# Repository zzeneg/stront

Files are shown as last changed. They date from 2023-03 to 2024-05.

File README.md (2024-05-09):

# stront

Family of modular split keyboards with 38 or 40 keys, LCD display and Cirque/Azoteq trackpad.

## Features

All versions:
- Hotswap sockets
- LCD display (1.69" 240x280 by default)
- Cirque or Azoteq (with VIK adapter) trackpad
- roller/rotary encoders
- 3D printed cases
- exposed SPI/I2C contacts, so any other device can be used instead, it's just a matter of changing the case

| | MX-40 | MX-38 | Choc |
| --- | --- | --- | --- |
| Number of keys | 40 | 38 | 38 |
| Supported switches | MX/KS<sup>[1]</sup>| MX/KS<sup>[1]</sup>| Choc v1 |
| Interconnect | USB-C | USB-C/TRRS | USB-C/TRRS |
| Interconnect | USB-C | USB-C/TRRS | USB-C/TRRS |
| [VIK](https://github.com/sadekbaroudi/vik) support | :heavy_check_mark: | :heavy_check_mark: | :x: |
| Module system | :heavy_check_mark: | :heavy_check_mark: | :x: |
| Splay | :x: | :x: | :heavy_check_mark: |

**[1]**: KS-33/KS-27 - Gateron Low Profile switches, not compatible with MX footprint and require special hotswap sockets

## Photos

#### MX-40 and MX-38 versions

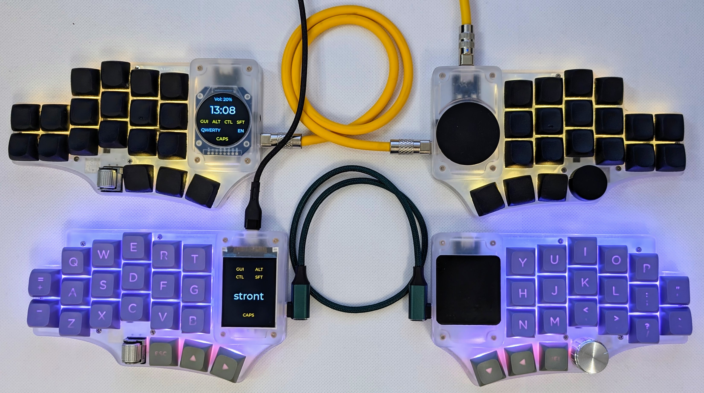
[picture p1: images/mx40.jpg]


#### MX-38 versions (MX and KS-33 switches)

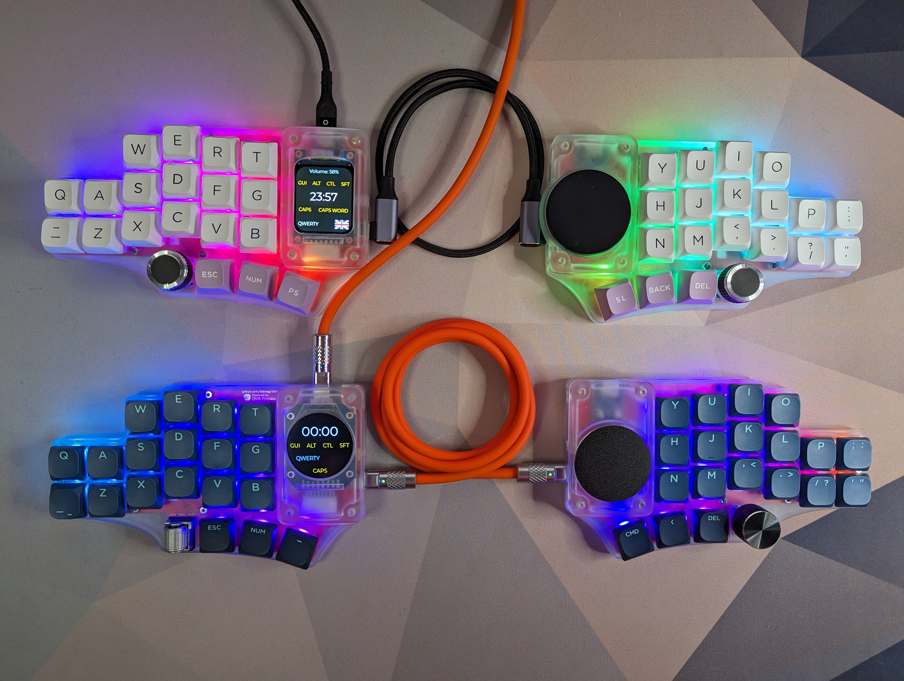
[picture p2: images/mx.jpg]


#### Choc version

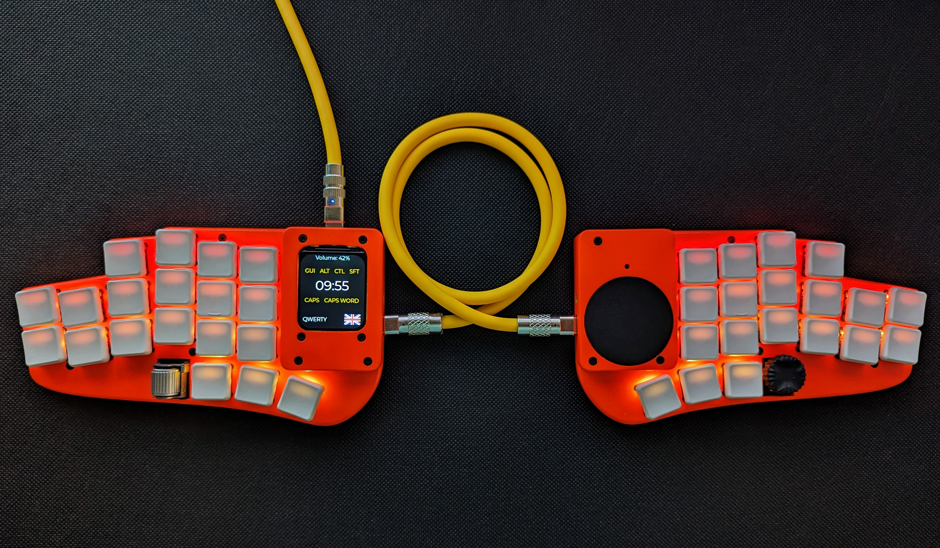
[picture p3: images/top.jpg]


#### Display with PC companion app

https://github.com/zzeneg/stront/assets/910255/bb812821-9b2b-454a-a9a5-45d696a1f5aa

## Available modules - MX38/MX40 versions only ⚠️

- LCD displays
  - ST7789 1.69" 240x280
  - ST7789 2" 240x320
  - GC9A01 round 1.28" 240x240
- Touchpads
  - Cirque 40mm flat
  - Cirque 40mm curved
  - Azoteq TPS43
  - Azoteq TPS65 (technically supported but I think it's too big)

## Firmware

[Companion app](https://github.com/zzeneg/qmk-hid-host) for Raw HID communication.

#### QMK

Please see main `config.h` and `rules.mk` for comments and available options.

- [source code](https://github.com/zzeneg/qmk_firmware/tree/stront/keyboards/stront)
- [pre-compiled files](https://github.com/zzeneg/qmk_firmware/releases/tag/stront)

#### Vial

- [source code](https://github.com/zzeneg/vial-qmk/tree/feature/zzeneg/keyboards/stront)
- [pre-compiled files](https://github.com/zzeneg/vial-qmk/releases/tag/zzeneg)

#### Compiled versions
> Each firmware name has two modules, first is on the left side, second on the right, e.g. if your keyboard has Azoteq on the left and round display on the right - choose `azoteq-round`

- keymaps:
  - `default` - sample keymap with home row mods. Not recommended for longer use - create your own.
  - `hid` - default keymap with HID support. Requires companion application.
  - `zzeneg` - my highly customized layout.
- hardware versions:
  - `-rect-` - rectangular display (ST7789 240x280)
  - `-round-` - round display (GC9A01 240x240)
  - `-flat-` - flat 40mm Cirque
  - `-curved-` - curved 40mm Cirque
  - `-azoteq-` - Azoteq TPS43

> [!WARNING]
> For 38keys version with VIK display adapter - redefine LCD pins in `config.h` as in 40keys version

## Build Guide

[MX38/MX40 versions](./build-guide/mx/readme.md)

[Choc version](./build-guide/choc/readme.md)

## VIK - MX38/MX40 versions only ⚠️

> [!NOTE]
> VIK is a standard for a data interface between printed circuit boards. It is intended to provide modularity between a mechanical keyboard PCB and additional features.

[VIK repository](https://github.com/sadekbaroudi/vik)

#### Certification card

| Category | Classification | Response |
| --- | --- | --- |
| FPC connector | Required | :heavy_check_mark: |
| Breakout pins | Recommended | :heavy_check_mark: |
| Supplies: SPI | Strongly recommended | :heavy_check_mark: <sup>[1]</sup> |
| Supplies: I2C | Strongly recommended | :heavy_check_mark: <sup>[1]</sup> |
| I2C on main PCB | Discouraged | No |
| I2C pull ups | Informative | Optional<sup>[2]</sup> |
| Supplies: RGB | Strongly recommended | :heavy_check_mark: |
| Supplies: Extra GPIO 1 | Required | Digital |
| Supplies: Extra GPIO 2 | Required | Digital |

**[1]**: I2C and SPI use same pins, so you can use only one or the other, not both. Selection is configured in firmware.

**[2]**: PCB has pads designed for 1206/3216 SMD resistors, you can solder them manually if needed.



#### VIK usage

Built-in display and trackpad use the same interface, so any additional VIK module will have to replace one of them (it's possible to combine other I2C modules with Azoteq). Depending on the size it can integrated into the cover or a standalone case.

All possible connectors support VIK - FPC horizontal on the back, FPC vertical on the front and the breakout pins.

## Support

If you like my work and want to support my future designs, please consider [sponsorship](https://github.com/sponsors/zzeneg), ordering from PCBWay using my shared projects - [Choc](https://www.pcbway.com/project/shareproject/Stront_low_profile_keyboard_85ec2664.html) or [MX38](https://www.pcbway.com/project/shareproject/Stront_MX_KS_33_keyboard_6a70e49a.html), or using [referral link](https://pcbway.com/g/3wpLAF) for signing up.

#### Sponsors

Thank you very much for your support!



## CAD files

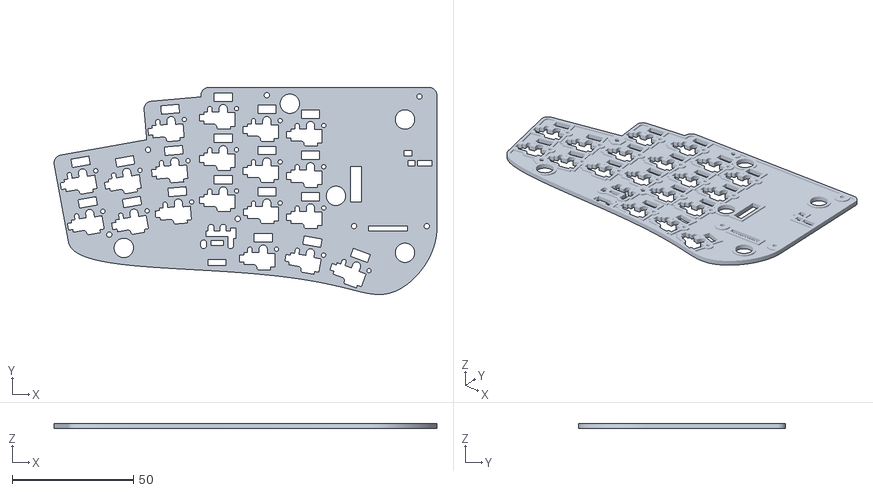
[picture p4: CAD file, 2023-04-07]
case/choc/bottom_case-choc v13_left-thin.stl
158.0 x 85.4 x 2.20

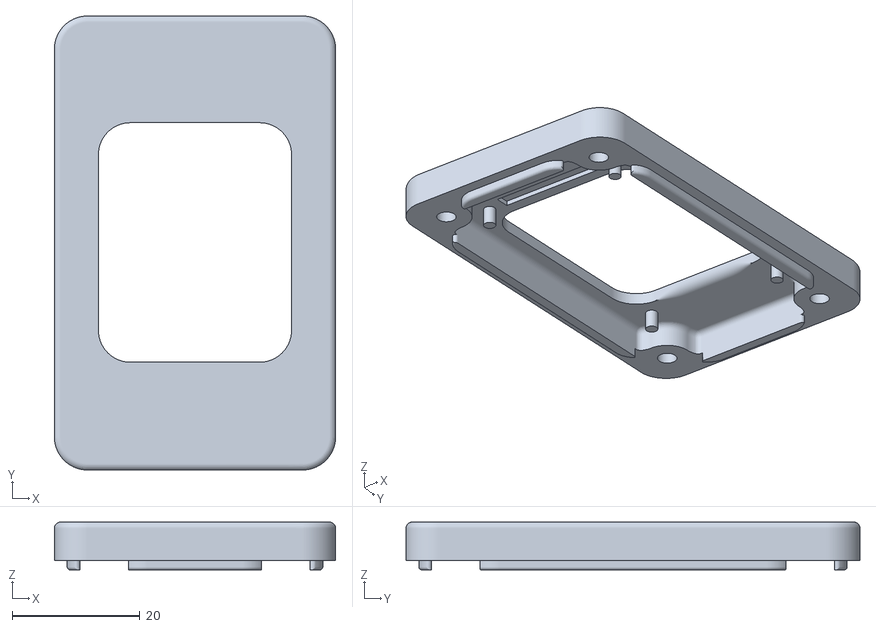
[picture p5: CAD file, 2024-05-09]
case/covers/display-1.69.stl
44.0 x 71.0 x 7.50

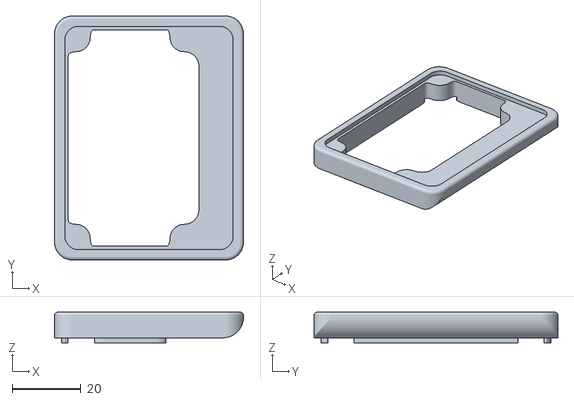
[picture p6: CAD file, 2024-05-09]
case/covers/untested/azoteq-tps65-left.stl
55.0 x 71.0 x 9.00

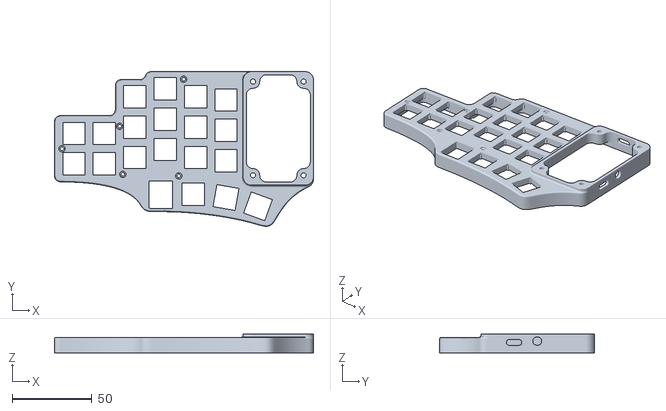
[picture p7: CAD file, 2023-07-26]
case/mx38/top_left-roller_plateHeight_5mm.stl
161.9 x 96.7 x 11.8

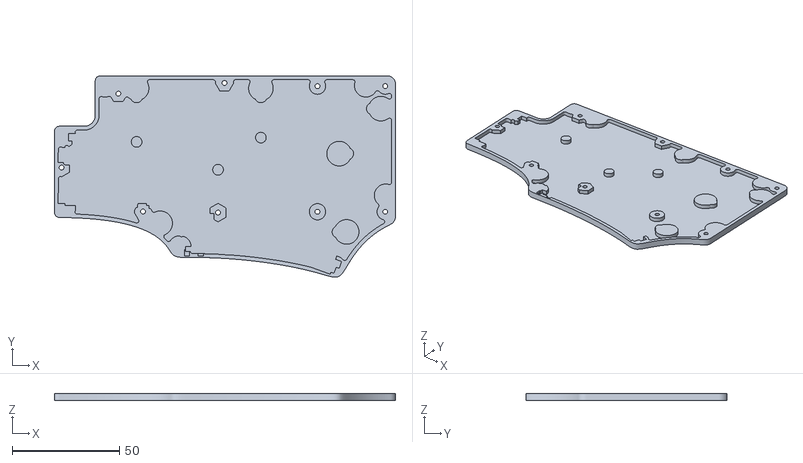
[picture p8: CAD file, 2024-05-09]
case/mx40/bottom_right.stl
159.1 x 93.9 x 3.20

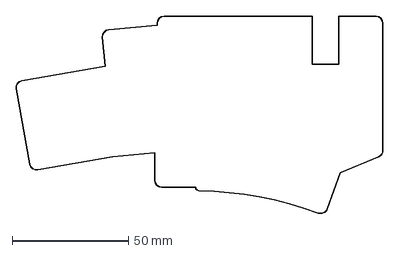
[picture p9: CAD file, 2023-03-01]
pcb/choc/pcb.dxf
157.6 x 84.7 mm

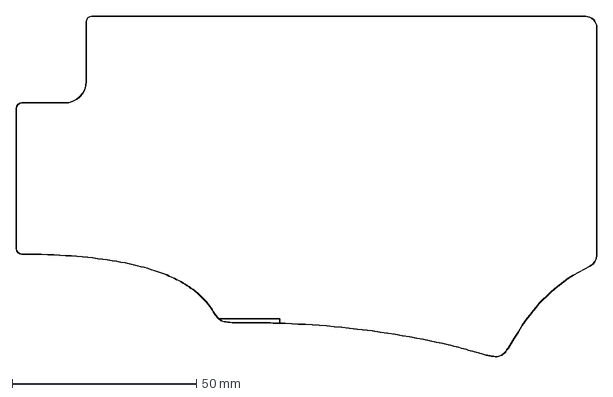
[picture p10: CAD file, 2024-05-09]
pcb/mx40/outline.dxf
157.5 x 92.3 mm

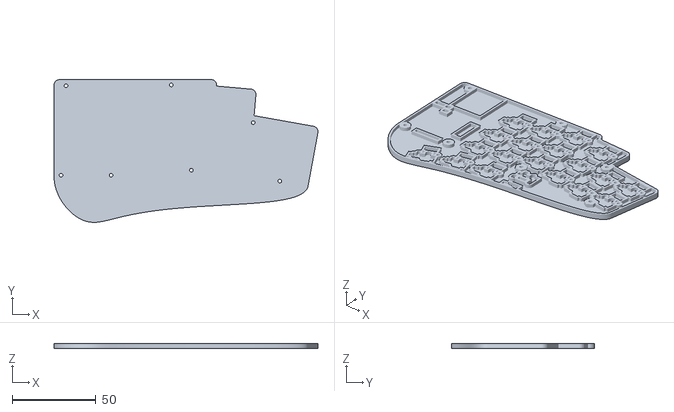
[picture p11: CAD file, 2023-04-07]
case/choc/bottom_case-choc v13_right.stl
158.0 x 85.4 x 3.20

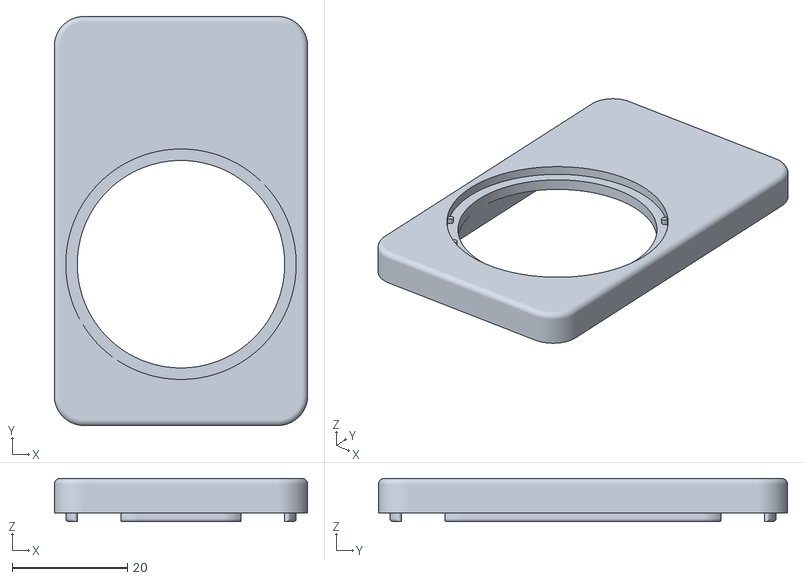
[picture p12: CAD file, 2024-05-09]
case/covers/cirque-40-flat_right.stl
44.0 x 71.0 x 7.50

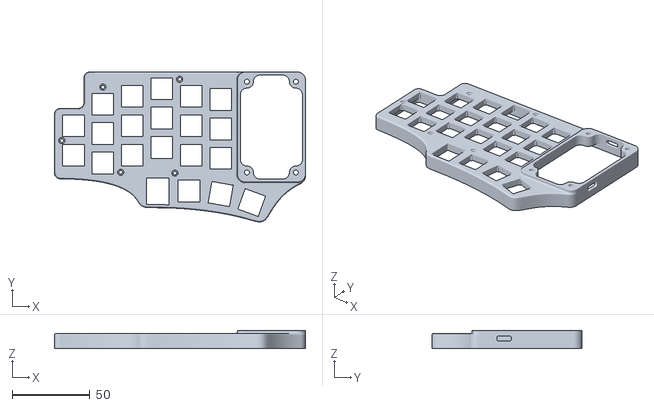
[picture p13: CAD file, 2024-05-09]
case/mx40/top_left-roller_plateHeight_5mm.stl
161.9 x 96.7 x 11.8

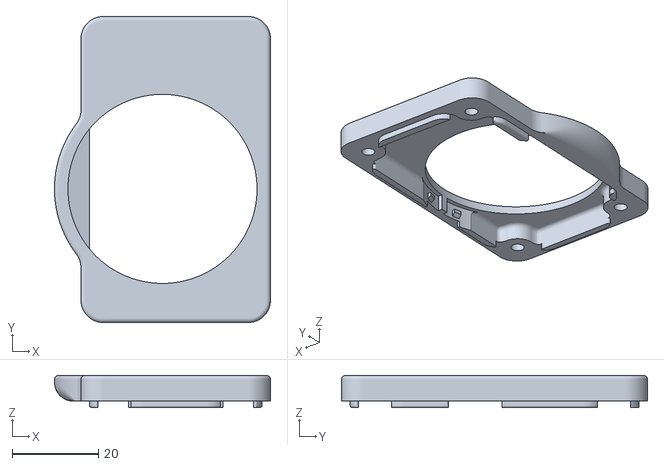
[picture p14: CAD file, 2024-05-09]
case/covers/cirque-40-curved_right.stl
50.1 x 71.0 x 7.50

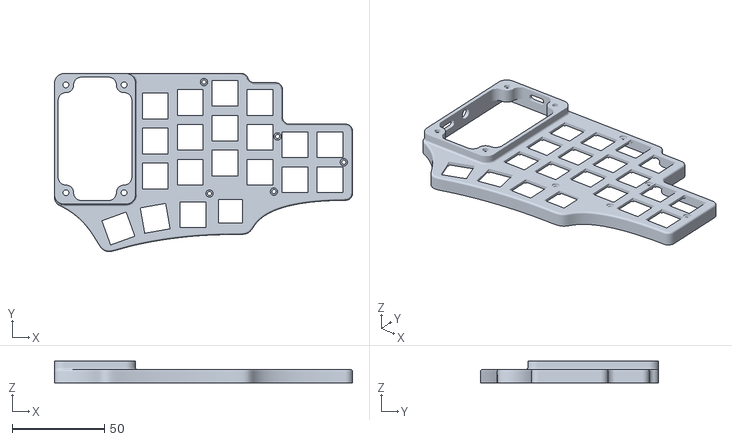
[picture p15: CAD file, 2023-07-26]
case/mx38/top_right_plateHeight_2.5mm.stl
161.9 x 96.7 x 11.8

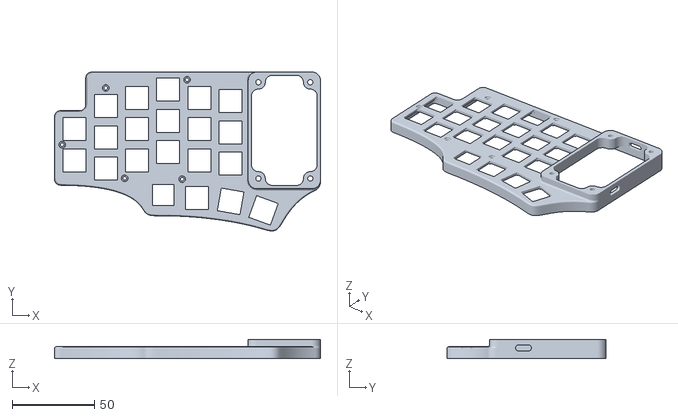
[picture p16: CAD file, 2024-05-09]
case/mx40/top_left-rotary_plateHeight_2.5mm.stl
161.9 x 96.7 x 11.8

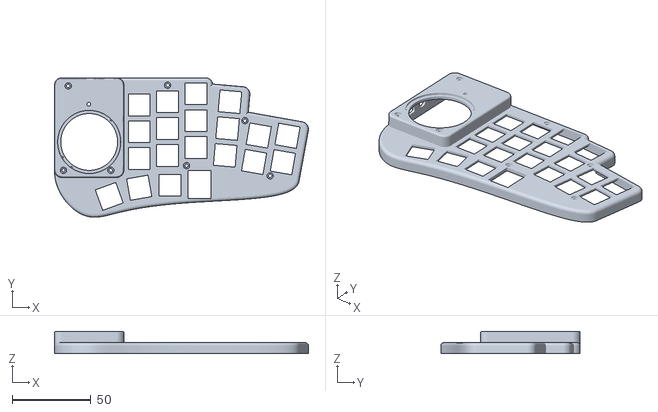
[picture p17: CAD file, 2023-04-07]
case/choc/top_case-choc v13_right.stl
161.0 x 88.4 x 14.2

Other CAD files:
case/mx38/top_right-roller_plateHeight_5mm.stl
case/choc/bottom_case-choc v13_right-thin.stl
case/covers/display-round.stl
case/mx38/top_right_plateHeight_5mm.stl
case/choc/border.dxf
case/choc/bottom_case-choc v13_left.stl
case/choc/top_case-choc v13_left-thin.stl
case/choc/top_case-choc v13_left.stl
case/choc/top_case-choc v13_right-thin.stl
case/covers/azoteq-tps43.stl
case/covers/azoteq-tps65-right.stl
case/covers/cirque-40-curved_left.stl
case/covers/cirque-40-flat_left.stl
case/covers/display-2inch.stl
case/mx38/bottom_left-shell.stl
case/mx38/bottom_left.stl
case/mx38/bottom_right-shell.stl
case/mx38/bottom_right.stl
case/mx38/outline.dxf
case/mx38/top_left-roller_plateHeight_2.5mm.stl
case/mx38/top_left_plateHeight_2.5mm.stl
case/mx38/top_left_plateHeight_5mm.stl
case/mx38/top_right-roller_plateHeight_2.5mm.stl
case/mx40/bottom_left.stl
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

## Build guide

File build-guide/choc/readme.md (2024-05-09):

# Build Guide

## Gerber files

- [PCB](/gerbers/choc.zip)

## Case files (3d printed)

All files are in [case/choc](/case/choc) folder.

- thin version - just cutouts for all elements, as low as it can be. May be combined with normal top case and metal bottom plate for additional weight. Has additional holes for 8mm magnets.
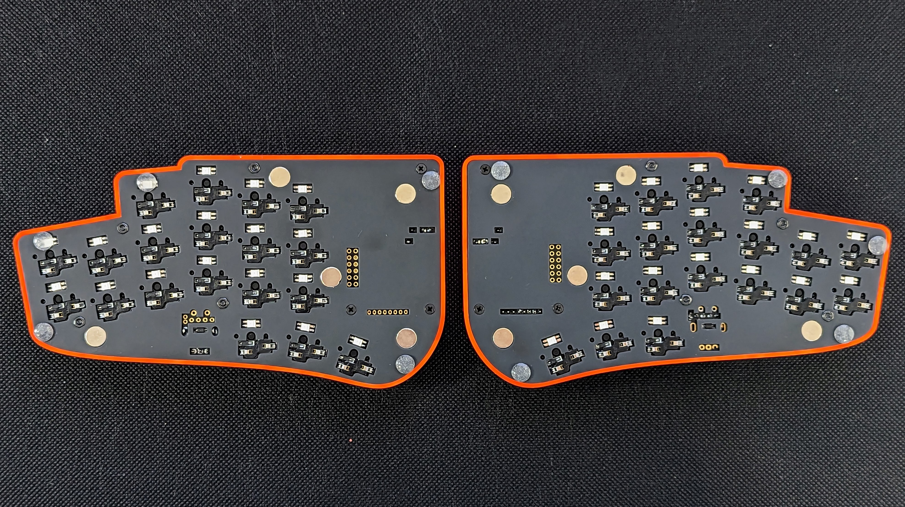
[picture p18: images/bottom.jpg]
  
- normal (1mm higher)
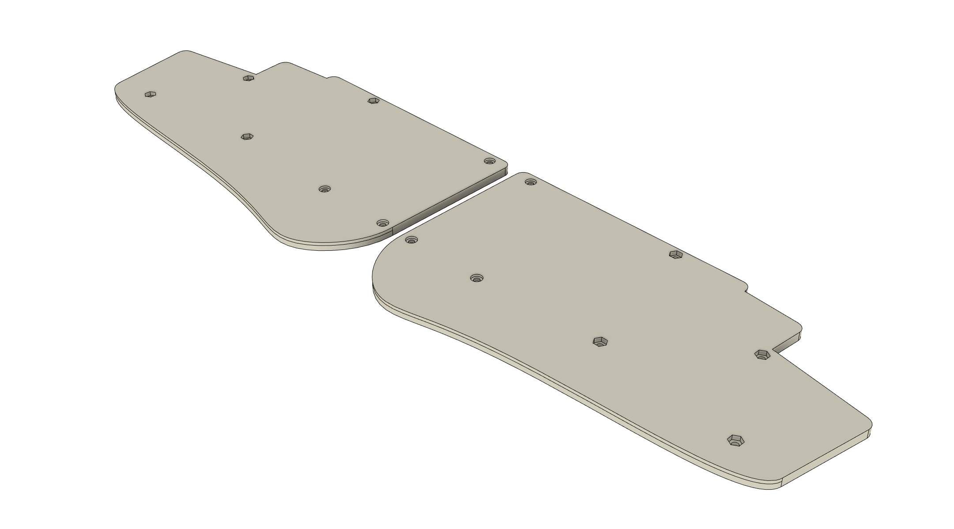
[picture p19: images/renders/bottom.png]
  

## Ordering

PCB was created in collaboration with [PCBWay](https://www.pcbway.com), so I've added their logo on the PCB. Feel free to remove it and/or use any other manufacturer, however I had very positive experience with PCBWay and their FR4 and silkscreen are high quality so I can definitely recommend them. And as EU customer I particularly liked their fast shipping options and ability to pay all taxes at once.

If you'd like to support me financially please consider ordering using my [shared project](https://www.pcbway.com/project/shareproject/Stront_low_profile_keyboard_85ec2664.html) or use [referral link](https://pcbway.com/g/3wpLAF) for signing up.

3D printed case can be printed at home or ordered from a manufacturer, I tested it with black/white resin.

## Materials

- PCBs
- Case (4 parts)
- 2 Waveshare [RP2040 Zero](https://www.aliexpress.com/item/3256804090654134.html) MCUs
- 38 [SMD SOD-123 1N4148](https://www.aliexpress.com/item/1005002882901030.html) diodes
- 2 [EC11/12 rotary encoder](https://www.aliexpress.com/item/33006686909.html) with [knob](https://www.aliexpress.com/item/1005003425428192.html) or [Panasonic EVQWGD001 roller encoder](https://www.aliexpress.com/item/32990950196.html)
- 8mm M2 female-female [standoffs](https://www.aliexpress.com/item/4001271908929.html)
- 5mm (and 6mm if normal case) M2 [screws with flat head](https://www.aliexpress.com/item/4001248931159.html)
- M2 [nuts](https://www.aliexpress.com/item/1005001412230125.html)
- [LCD 1.69" 240x280 display](https://www.aliexpress.com/item/1005004922900927.html)
- Right angled PH2.0 8pin [male connector](https://www.aliexpress.com/item/1005003115054198.html)
- PH2.0 8 pin [female connector with wires](https://www.aliexpress.com/item/4000130210271.html)
- 40mm flat Cirque trackpad (I2C or SPI)
- Vertical 12pin FFC/FPC [connector](https://www.aliexpress.com/item/10000000737049.html)
- 12pin 0.5mm pitch 10cm [FFC cable](https://www.aliexpress.com/item/1005002468369055.html) - grab both reverse and forward variants, in case you solder the connector upside down
- TRRS [connectors](https://www.aliexpress.com/item/4000661212458.html) and [cable](https://www.aliexpress.com/item/1005003676559658.html)
- USB-C [16pin connectors](https://www.aliexpress.com/item/1005003670899595.html) and [cable](https://www.aliexpress.com/item/1005004649061153.html) - optional
- [RGB LEDs 3mA](https://www.aliexpress.com/item/1005003636607308.html)
- Rubber [sheet](https://www.aliexpress.com/item/1005003938672544.html) or [7x1.5 legs](https://www.aliexpress.com/item/1005002995402961.html)
- 8mm magnets (if needed) - 2mm for rubber sheet version, 3mm for regular legs

## Tools

- Soldering iron. Any iron will work, but I highly recommend something small like TS100 or Pinecil with TS-K tip, it's good for SMD soldering
- Solder, preferably with lead if you can get one. For EU I recommend this [shop](https://botland.store) and Cynel brand. 0.56mm is great for SMD, and you can optionally get 0.9mm for hotswap sockets
- [Soldering paste](https://www.aliexpress.com/item/4000602425410.html)
- [Flux](https://www.aliexpress.com/item/1005004441105643.html)
- Tweezers (I prefer [reverse](https://www.aliexpress.com/item/1005004188266714.html) instead of regular), pliers, soldering mat, isopropyl alcohol (IPA) and [cotton pads](https://www.aliexpress.com/item/1005003798227116.html) for cleaning

## Build

Start with breaking the combined PCB into two halves using pliers. You can sand down the breaking points or just polish with a sharp knife. Just a bit, small pieces of PCB material are pretty bad for breathing in. Choose left or right half and place it upside down, we'll start from bottom side.

### LEDs

First of all, LEDs can be destroyed with heat, so be careful - use lower temp (something like 300C or lower depending on your solder) and don't hold the iron longer that needed. Second, be careful with placing the LED, they are not symmetrical. One pin (ground) is chamfered, it must be placed on a pad with similar shape (left bottom if you look on it).

There are several ways of soldering them, my favorite is:

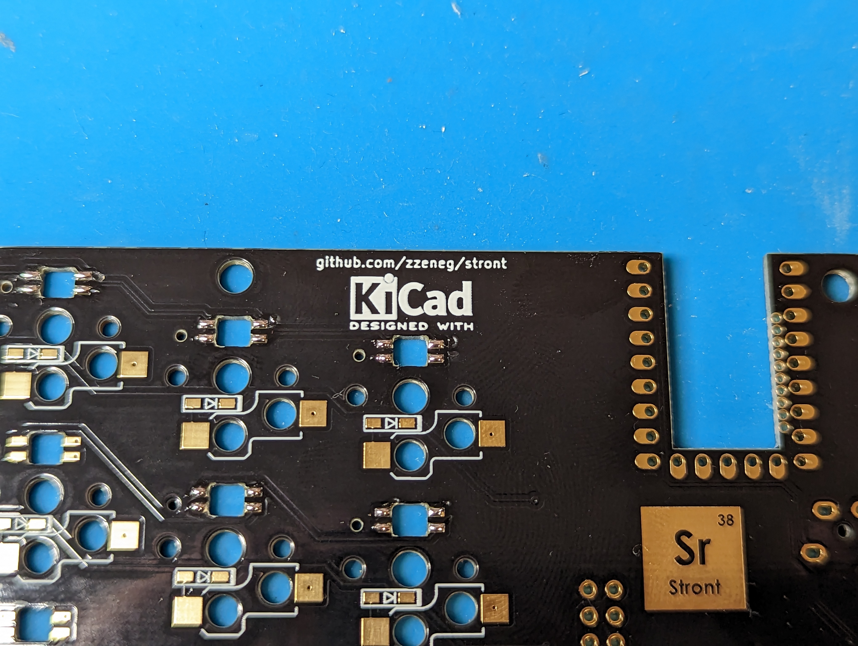
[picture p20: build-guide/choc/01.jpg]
- pre-tin all 4 pads 
- put a LED into place and press it gently with your fingernail or tweezers
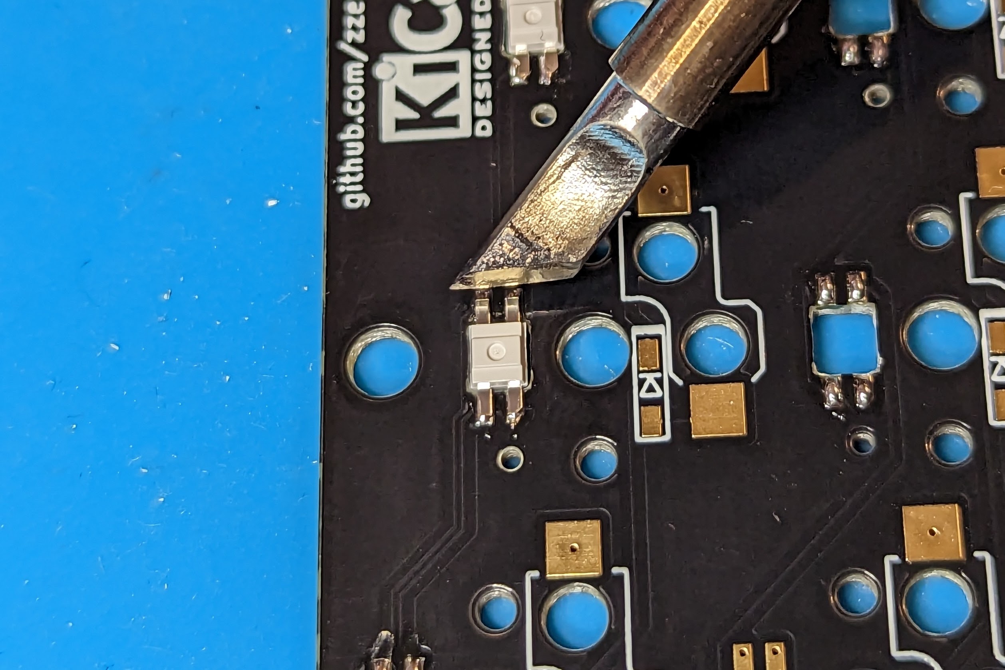
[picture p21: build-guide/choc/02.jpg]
- use TS-K tip to heat two pads and pins at the same time 
- do the same for other two pins
- repeat it for all LEDs

If you don't have a TS-K tip, just do all the pins one by one. The most important thing is to heat pin and pad simultaneously, otherwise you may have cold joints. You can experiment with solder paster and/or flux but I felt like it takes more time without any benefits.

### Diodes

Again, orientation is important. Every diode has a vertical line on it marking the side with cathode, experiment with lighting and angle if you don't see it.
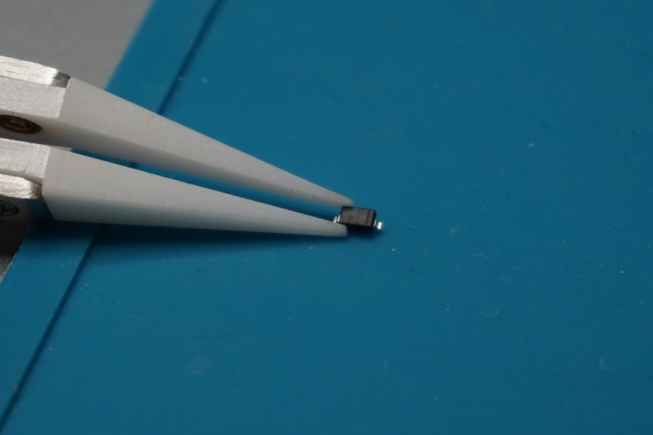
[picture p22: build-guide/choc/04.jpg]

On the PCB cathode is marked with a thick outside line and a vertical line between pads. Here on the photo cathode pad is tinned.
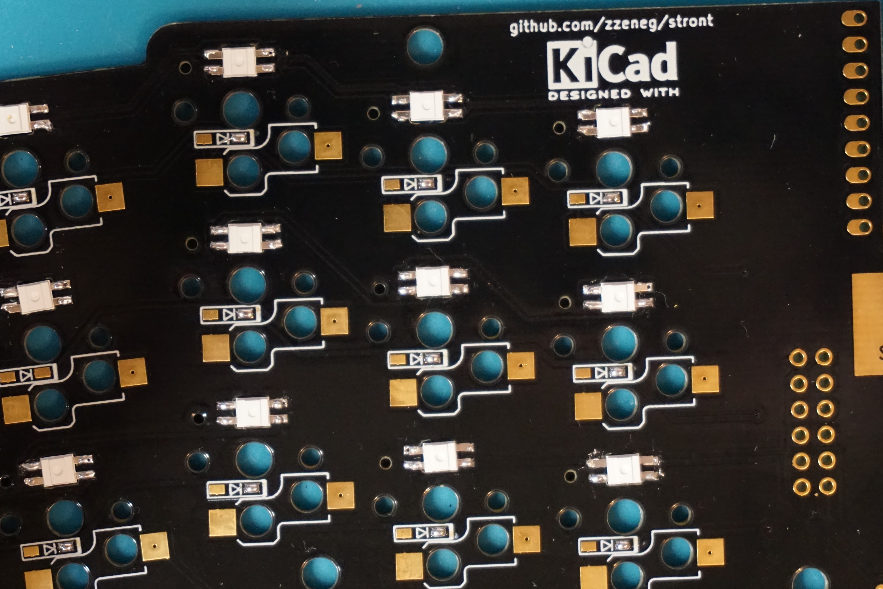
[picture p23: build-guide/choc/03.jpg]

Soldering order:

- tin one pad (doesn't really matter which one, what's important is consistency)
- grab a diode with tweezers and make sure it's oriented correctly
- place it next to the tinned pad, heat the solder blob, put the diode to its place and press it down with fingernail
- solder the second pin by simultaneously heating the pad, pin and solder wire

Repeat it for all diodes, then clean everything with IPA.

### Hotswap sockets

These are also asymmetrical but orientation does not really matter. You can still orient all of them in same way, border lines on PCB should help with that. If you have thick solder wire - use it, you'd need much more solder here compared to LEDs/diodes. Soldering process is the same as for diodes - pre-tin one side, put the socket, heat solder and push it into place. Solder second pin, repeat for all others.
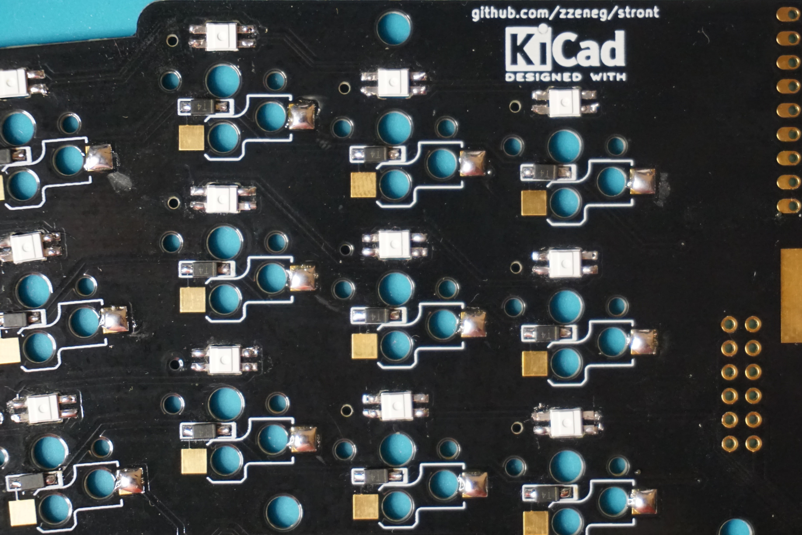
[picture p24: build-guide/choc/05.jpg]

Clean it with IPA, it's a bit harder with sockets but do your best.

### MCU

We're done with bottom side, so **FLIP THE PCB**. MCU goes on top side, so triple check it, you really-really don't want to solder it on the bottom side (I did it once so I know what I'm talking about). Also, I recommend to flash the MCU before soldering, I didn't see a dead one yet but you never know. Connect it to the computer and put a [precompiled firmware file](./../firmware/qmk/stront_default.uf2) into a disk that would appear.

I like to solder only castellated holes (edges) on MCU by holding my tip like this:
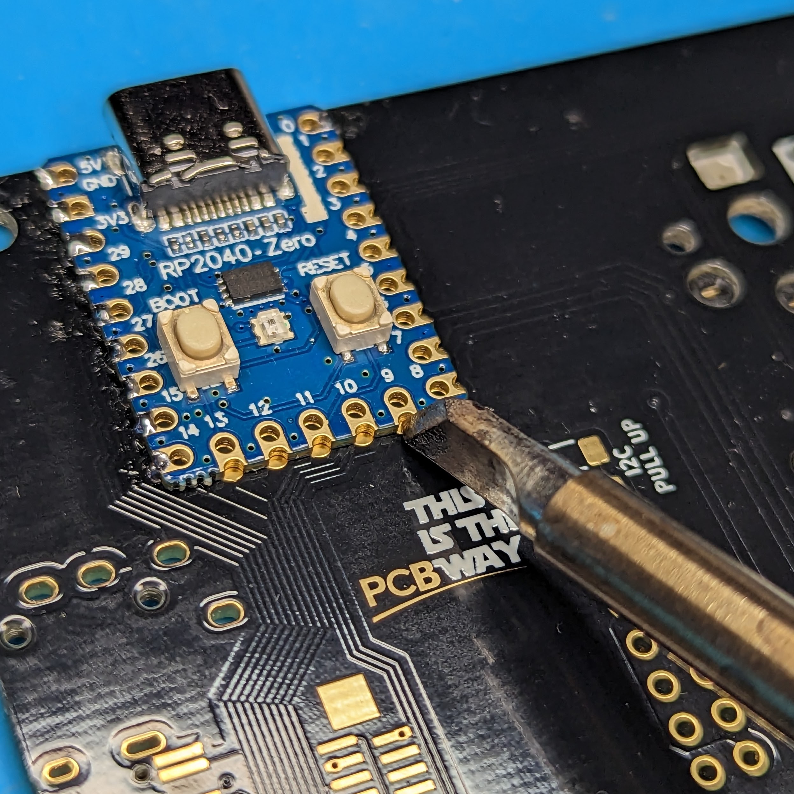
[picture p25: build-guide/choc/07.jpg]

Soldering process:

- pre-tin one (any) pad
- place the MCU on pads, heat the pre-tinned pad and move MCU into correct place (all holes must match), you can use pinhead/socket row to align it
- solder a pad on the opposite side of the MCU to hold it in place
- go through all pads one by one and solder them
- double check everything, it may be tricky to solder the PCB's pads sometimes but it's easy to spot it (see pad 5)
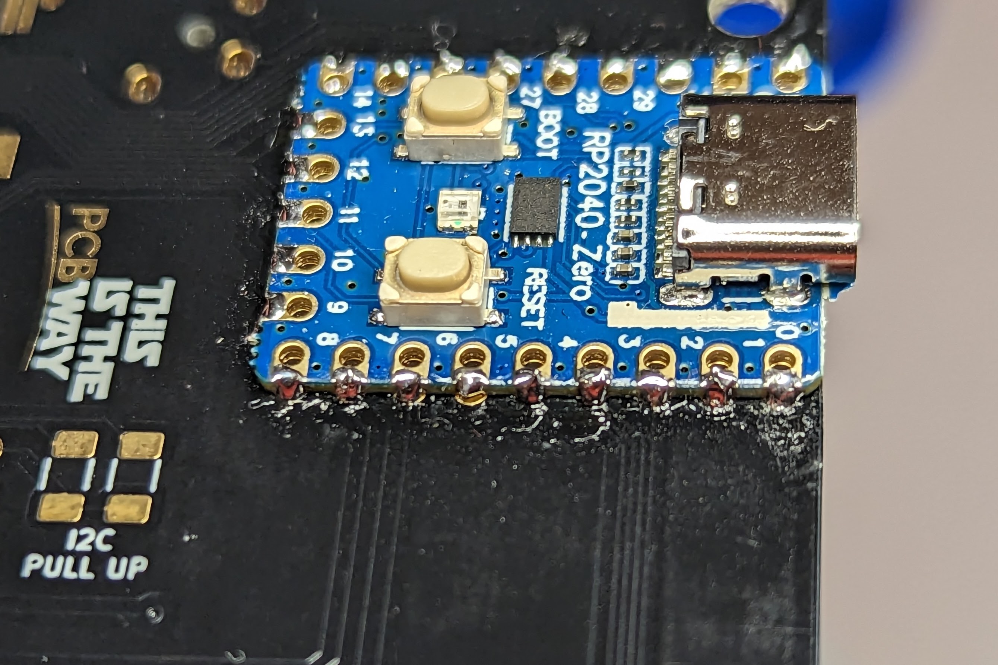
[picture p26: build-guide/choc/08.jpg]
  

### USB-C connector

It's a tricky one, solder paste and flux will simplify the process a lot but it's possible to do it without them.

- put the solder paste on the pads, it's better to add less than too much
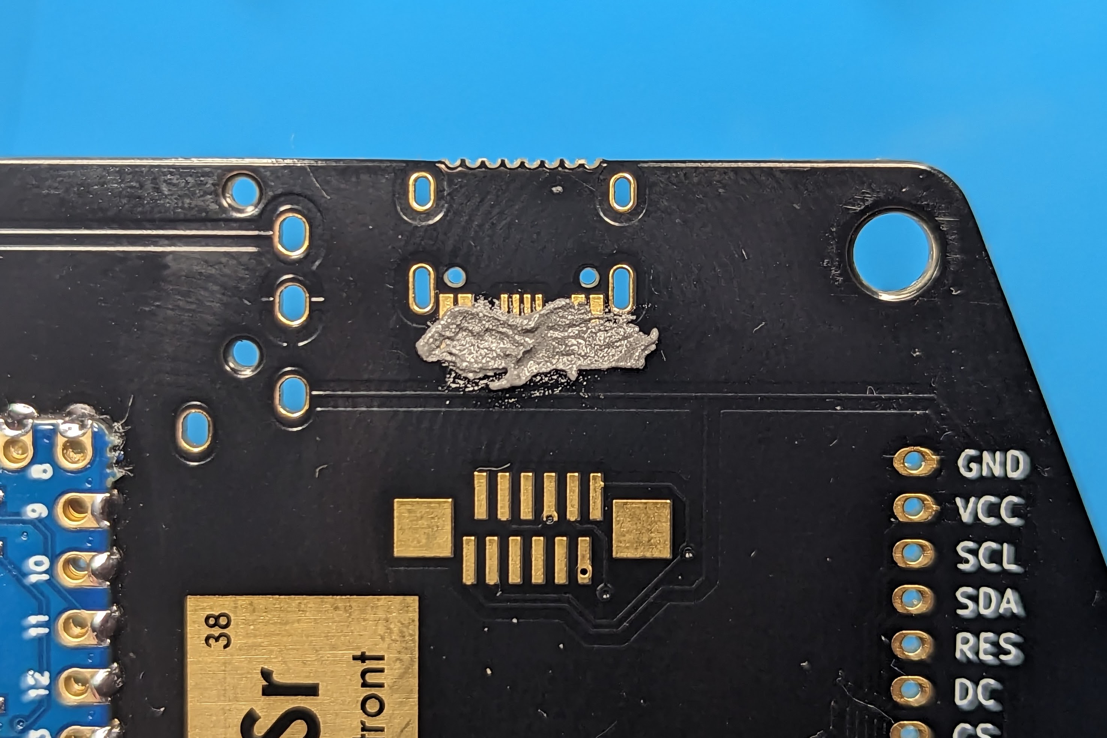
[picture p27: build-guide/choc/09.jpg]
  
- insert the connector into holes and solder one leg from the bottom side (just to hold it in place)
- carefully heat the pads and solder paste. Move tip from the connector to outside and remove extra solder
- if some pins are shorted - add flux (not paste!) and continue removing extra solder, be patient with it
- if pins are still shorted - desolder it completely and restart the process with a new connector
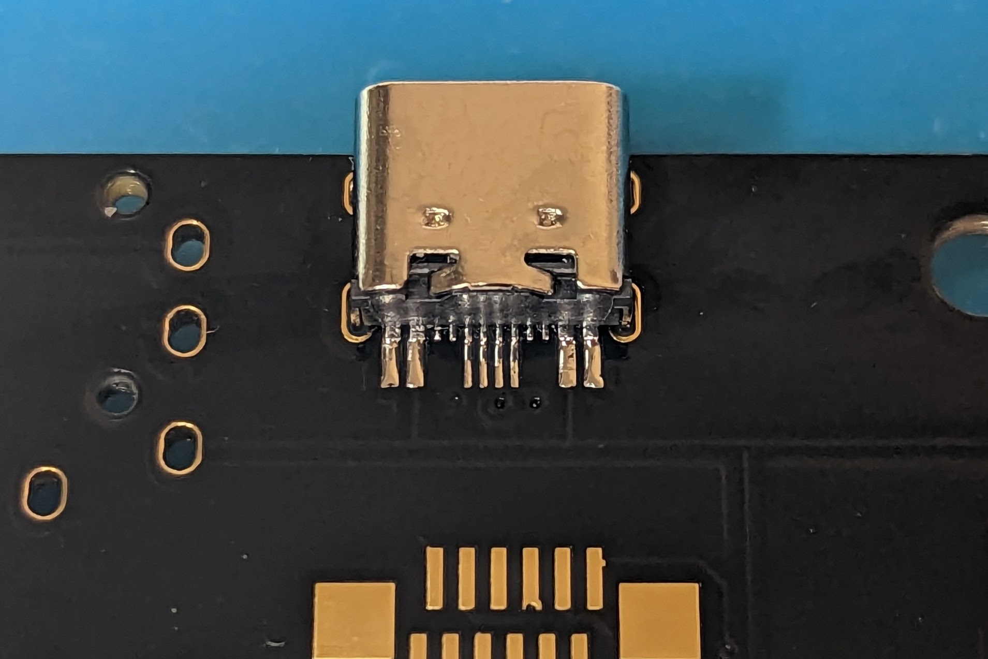
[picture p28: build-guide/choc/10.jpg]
  
- when pads are done, solder other legs from bottom side, add more solder to make sure it's firmly soldered but remove extras afterwards (solder must be flat with PCB, no blobs)
- I recommend to solder legs on top side as well but not sure it's possible without TS-K or any other sharp tip
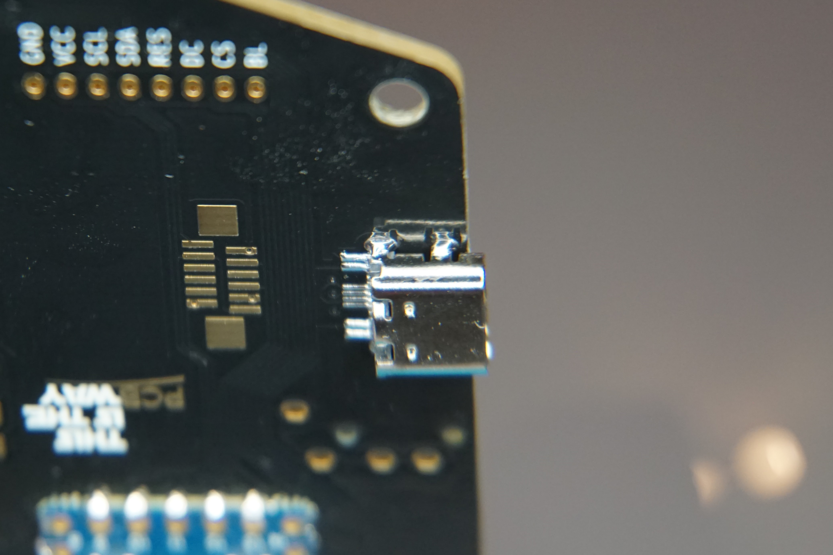
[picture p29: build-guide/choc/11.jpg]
  

**DO NOT CONNECT THAT USB-C TO YOUR PC, IT'S ONLY FOR INTERCONNECT BETWEEN LEFT AND RIGHT SIDES**

### TRRS connector

Even if you'd like to use USB-C exclusively I still recommend to add TRRS just in case. It's super easy (I didn't even take a photo of it, sorry).

### Second half - repeat all previous steps

### Cirque touchpad

Pretty similar to USB-C connector but easier thanks to 1mm space between pins. Also if you fail the step you can use a [daughterboard](https://www.aliexpress.com/item/4001156449357.html)(0.5mm pitch, 12 pins), it matches the holes on the PCB.

- take **right** PCB
- put paste on pads, make sure to leave empty space in the middle
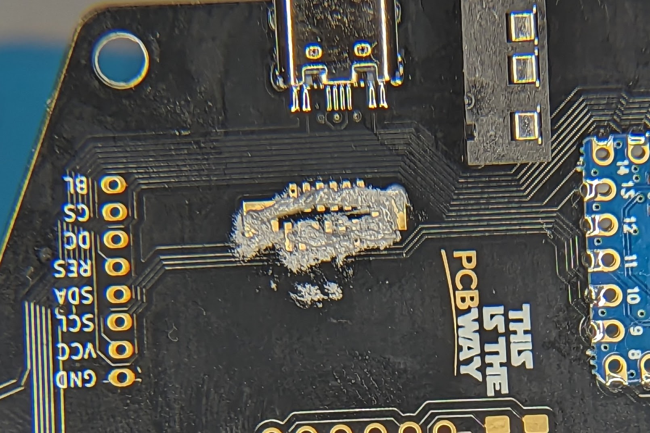
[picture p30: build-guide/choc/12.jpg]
  
- place connector with black moving part facing the switches (if you messed up here, don't worry and just use another cable during assembly)
- start soldering with small pads on one side by carefully moving the tip from connector to outside and removing extra solder
- when connector is placed correctly go the second side
- make sure there are no shorts and then solder two big pads
- you can desolder and restart in case of shorts or bad placement
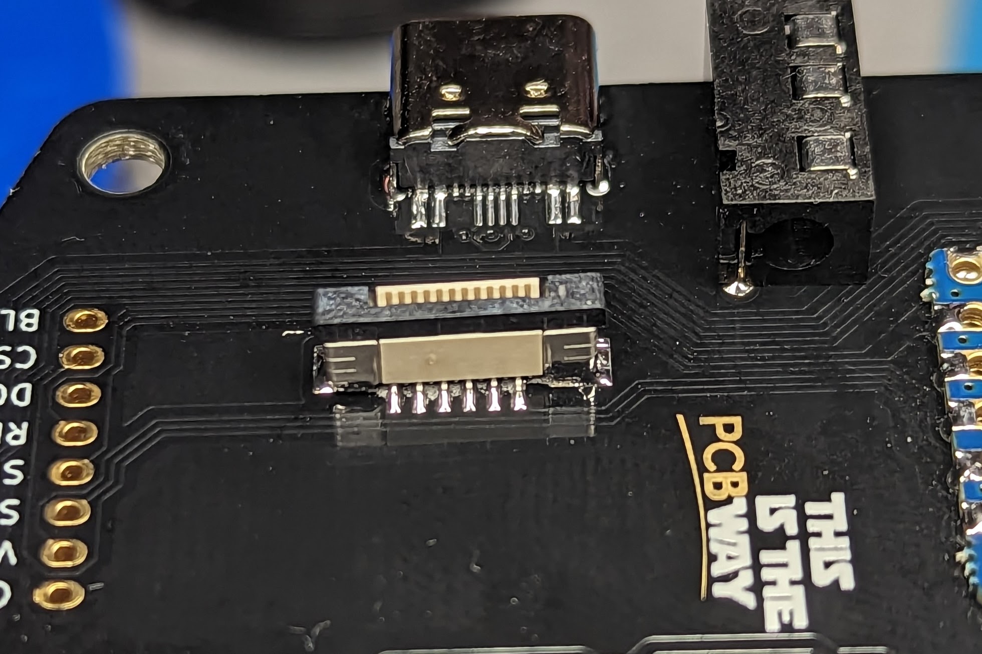
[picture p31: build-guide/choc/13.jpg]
  

Insert Cirque touchpad into the case, add hotglue it from bottom. There is only one position possible so you can't do it wrong (I hope). Ignore standoffs from the photo for now.
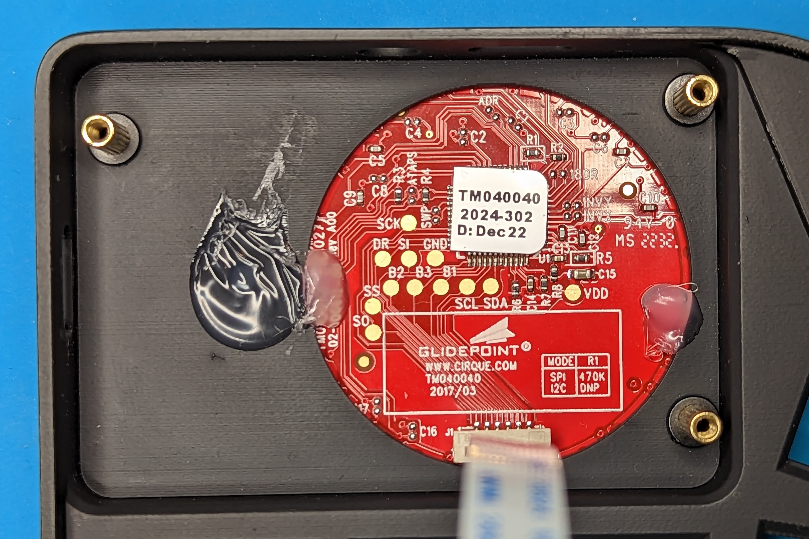
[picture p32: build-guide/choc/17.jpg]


### Display

Start with adding male connector to **left** PCB (forgot to take an actual photo so that's a staged one without other components that should be already soldered for you)
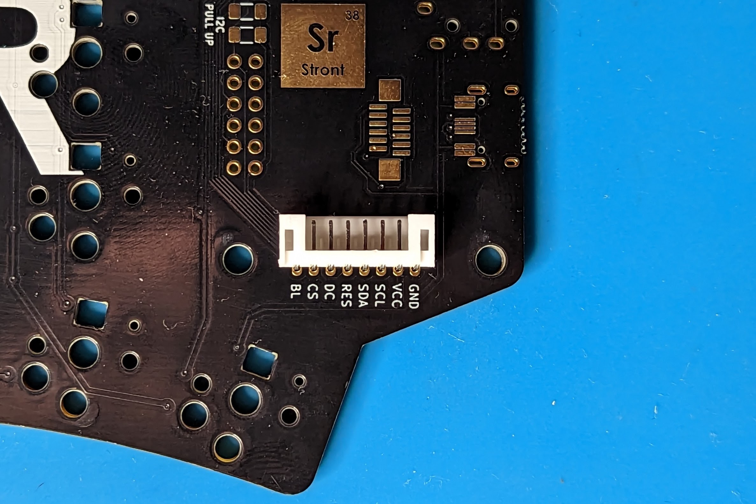
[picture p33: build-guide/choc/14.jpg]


Take a female connector with wires and cut them to 5cm. Make sure the connector is correctly oriented (when inserted into PCB the display should be facing up) and solder them. Cut wires/solder blobs on top afterwards so that display's PCB is flat. You can hotglue wires to display to secure them in place.
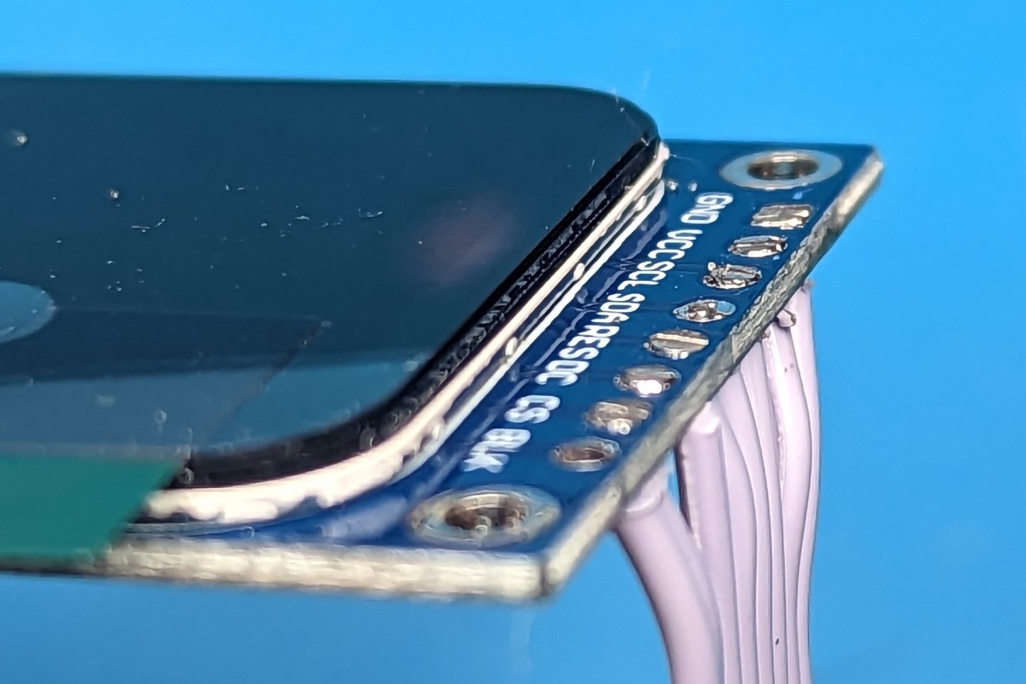
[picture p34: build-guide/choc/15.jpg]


### Testing/flashing

At this point you can connect everything and test the keyboard. Again, be extra careful with USB-C ports.

- grab default [pre-compiled firmware](./../firmware/qmk/stront_default.uf2)
- connect one side to PC and go into bootloader by double pressing reset button
- copy the file onto the disk that would appear
- repeat for second half
- firmware has [EE_HANDS](https://docs.qmk.fm/#/feature_split_keyboard?id=handedness-by-eeprom) enabled so any side can be master. You'd have to specify left or right side by pressing key combinations - hold inner thumb key, then hold outer thumb key to activate SYSTEM layer. Now press outer bottom pinky key for left side or inner bottom index key for right side (insert switches into those places). E.g.

  - if your left side is detected as right side, do this:

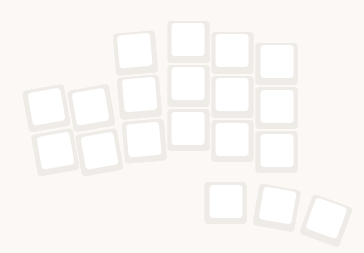
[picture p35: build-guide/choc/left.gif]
  

  - if your right side is detected as left side, do this:

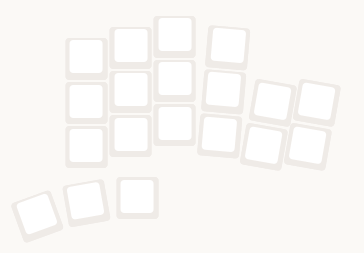
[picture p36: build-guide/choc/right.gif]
  

  See [keymap](https://github.com/zzeneg/qmk_firmware/blob/feature/stront/keyboards/stront/keymaps/default/keymap.c) for better understanding. **Reconnect the keyboard to apply changes.**

- test display and touchpad
- test all keys - insert swithes or short sockets with something like metal tweezers or TRRS cable
- test encoders
- test USB-C interconnect in all 4 possible cable positions
- test LEDs - press or lightly tap each LED with your fingers to make sure the soldering is fine, there should be no flickering
- in case of any issues go to troubleshooting section

### Assembly

- use three 5mm screws and nuts to attach the display to the case
- add three 5mm screws and 8mm standoffs (I had only 7mm ones so I added 1mm washers on the photo, ignore them)
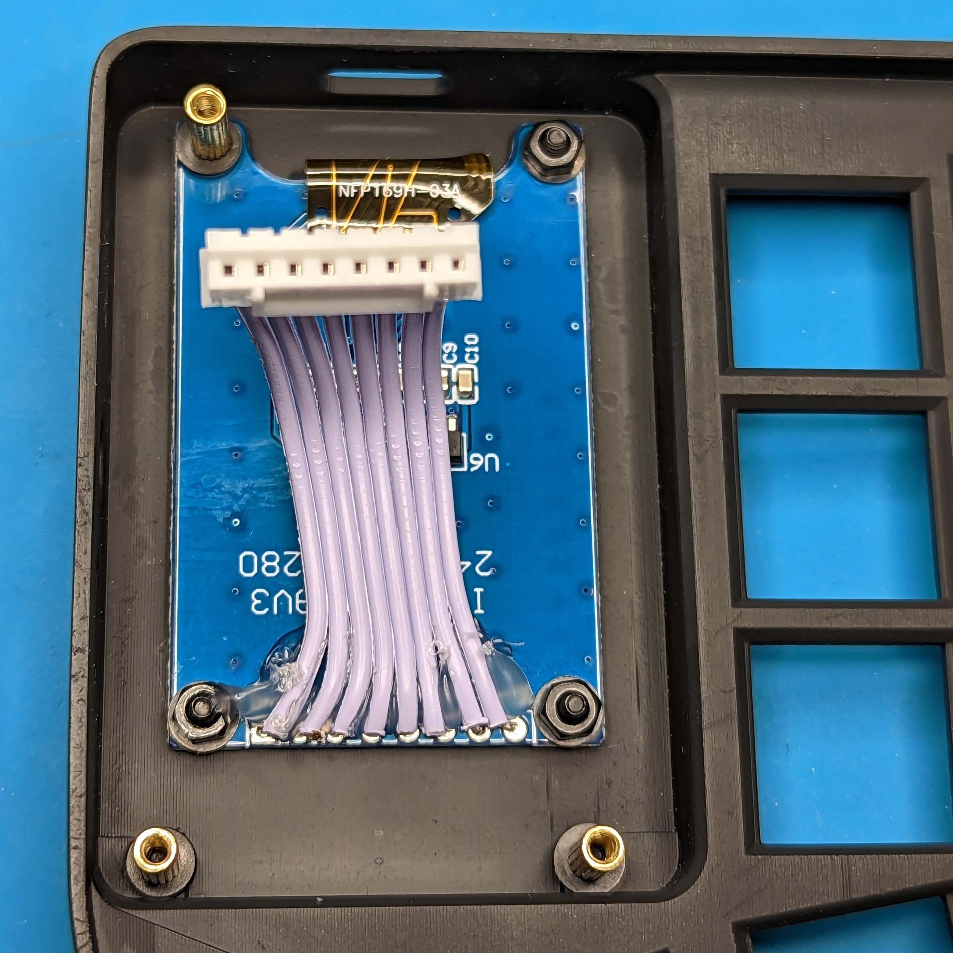
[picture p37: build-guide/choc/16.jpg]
  
- connect display, use tweezers/pliers if needed
- connect touchpad to PCB using reverse cable. If you soldered the FPC connector in the wrong way - use forward cable instead
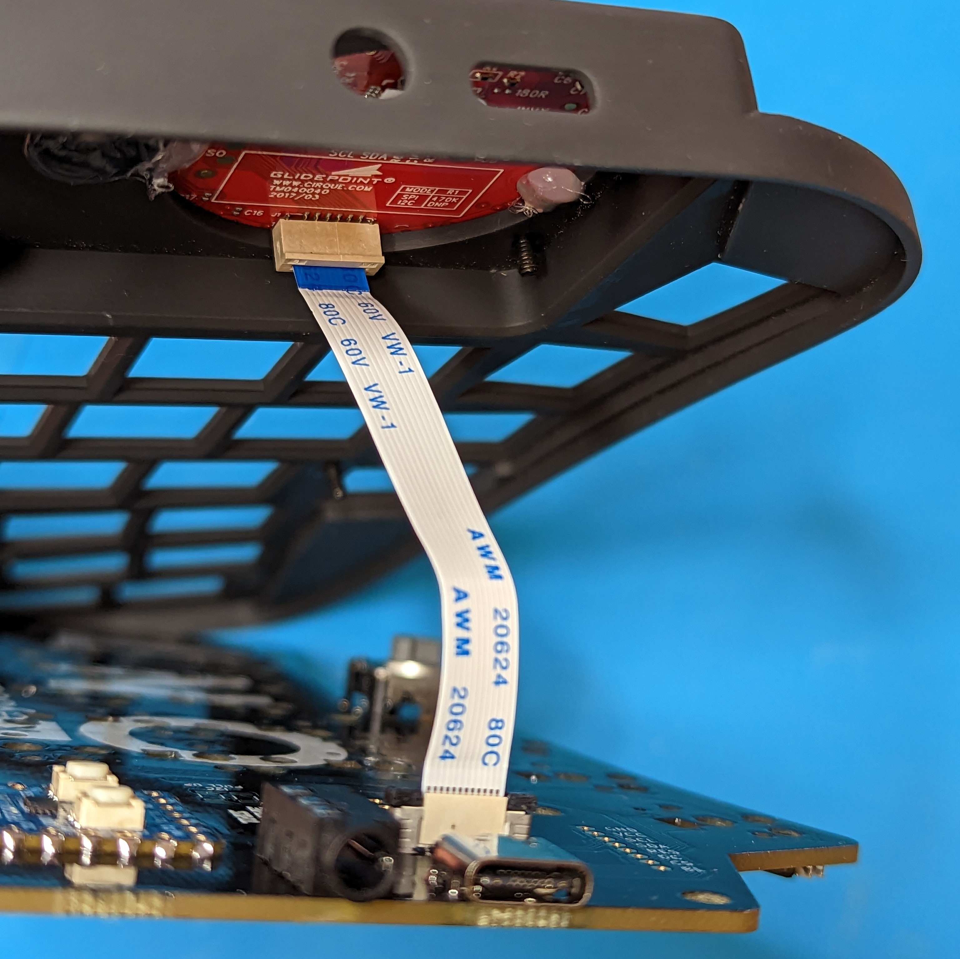
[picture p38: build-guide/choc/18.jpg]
  
- carefully insert PCB into case. Inserting USB-C/TRRS connectors will require just a bit of force
- attach bottom case, add 3 screws from bottom side (near display/touchpad)
- insert 4 nuts into bottom part, add 5mm (or 6mm for high case version) screws from top side
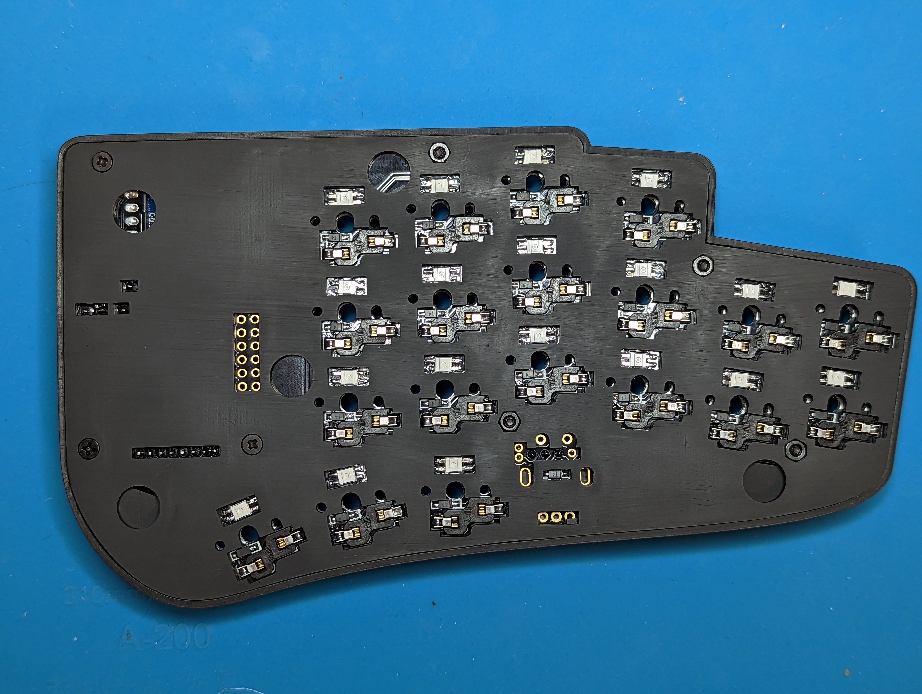
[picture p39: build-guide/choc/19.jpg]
  
- add magnets/rubber sheet/legs if you wish

### Troubleshooting

#### Slave side does not work at all

- try to connect it directly to PC
- check that you configured right/left side during/after flashing ([EE_HANDS](https://docs.qmk.fm/#/feature_split_keyboard?id=handedness-by-eeprom))
- if you use USB-C try TRRS instead
- try another interconnect cable
- check soldering for USB-C and TRRS connectors

#### Whole row/column does not work

- check soldering on controller pins, use schematic to trace problematic row/column to an exact pin

#### Single key does not work

- check that hotswap socket and diode are soldered correctly
- short hotswap socket manually, if it works - move the hotswap springs closer to each other

#### Multiple LEDs do not work

- LEDs are wired sequentially so check the last working one and first non-working, see schematic for correct order (it's not obvious)
- press or lightly tap LEDs with fingers/tweezers to check for bad soldering
- reflow solder on LED pins
- usually a dead LEDs if the least possible scenario, so make sure to check for everything else before desoldering

#### Display does not work

- check that you configured right/left side during/after flashing ([EE_HANDS](https://docs.qmk.fm/#/feature_split_keyboard?id=handedness-by-eeprom))
- check soldering on display/connector

#### Touchpad does not work

- check that you configured right/left side during/after flashing ([EE_HANDS](https://docs.qmk.fm/#/feature_split_keyboard?id=handedness-by-eeprom))
- check soldering on connector
- check that FPC cable is a correct one (forward/reverse) and is correctly inserted (use my photo as a reference)
- check for continuity using pads on Cirque trackpad, use schematic to trace correct pins on MCU

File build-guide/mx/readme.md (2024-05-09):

# Build Guide

The build process is the same for 38 and 40 keys versions, but files are different, please order carefully.

## Gerber files

- Main PCB - [mx40](/gerbers/mx40.zip) or [mx38](/gerbers/mx38.zip)
- for Azoteq touchpad only - [VIK adapter](https://github.com/sadekbaroudi/vik/tree/master/pcb/azoteq-tps) (or solder wires directly instead)
- for bare 2" display only - [VIK adapter](https://github.com/zzeneg/vik-display-adapter) (universal pcb 0.7/0.8mm pitch - **must** match your display)

## Case files (3d printed)

Main files - in [mx40](/case/mx40) and [mx38](/case/mx38) folders:

- 5mm plate for MX switches
- 2.5mm plate for KS-27/KS-33 switches
- versions for `rotary` and `roller` encoders

Covers - in [covers](/case/covers) folder:

- `left`/`right` versions for asymmetric covers

## Materials

- PCBs
- 3D printed case (6 parts)
- 38/40 switches (MX or KS-33/27)
- 38/40 hotswap sockets ([MX](https://www.aliexpress.com/item/1005004337532370.html) or [KS-33/27](https://www.aliexpress.com/item/1005005931500291.html))
- 38/40 [RGB LEDs 3mA](https://www.aliexpress.com/item/1005003636607308.html)
- 2 Waveshare [RP2040 Zero](https://www.aliexpress.com/item/3256804090654134.html) MCUs
- 42 [SMD SOD-123 1N4148](https://www.aliexpress.com/item/1005002882901030.html) diodes
- 2 [EC11/12 rotary encoder](https://www.aliexpress.com/item/33006686909.html) with [knob](https://www.aliexpress.com/item/1005003425428192.html) or [Panasonic EVQWGD001 roller encoder](https://www.aliexpress.com/item/32990950196.html)
- 8mm (ideally 9mm) for MX or 6mm for KS, 14mm for covers [M2 screws with flat head](https://www.aliexpress.com/item/4001248931159.html)
- M2 [nuts](https://www.aliexpress.com/item/1005001412230125.html)
- M2 [heatset inserts](https://www.aliexpress.com/item/1005004624377733.html) - 4mm length, 3.2mm diameter for resin case or 3.5mm for Nylon/PLA
- One display:
  - LCD 1.69" 240x280 [display](https://www.aliexpress.com/item/1005004922900927.html)
  - LCD 1.28" round [display](https://www.aliexpress.com/item/1005004069703494.html) - "square" option, with 8 corners
  - Bare LCD 2" 240x320 [display](https://www.aliexpress.com/item/1416043398.html) - **VIK adapter required** (that link uses 0.8mm pitch, others may use 0.7mm)
- One touchpad:
  - Cirque 40mm with flat or curved overlay
  - Azoteq TPS43 + some vinyl sheet as overlay
- Right angled PH2.0 8pin [male connector](https://www.aliexpress.com/item/1005003115054198.html)
- PH2.0 8pin [female connector with wires](https://www.aliexpress.com/item/4000130210271.html)
- [Vertical](https://www.aliexpress.com/item/10000000737049.html)/[horizontal](https://www.aliexpress.com/item/4000106123266.html) 12pin FFC/FPC connectors
- 12pin 0.5mm pitch 6cm/10cm [FFC cable](https://www.aliexpress.com/item/1005002468369055.html) - **both reverse and forward variants**
- TRRS [connectors](https://www.aliexpress.com/item/4000661212458.html) and [cable](https://www.aliexpress.com/item/1005003676559658.html) - **38 keys version only**
- USB-C [16pin connectors](https://www.aliexpress.com/item/1005003670899595.html) and [cable](https://www.aliexpress.com/item/1005004649061153.html)
- [7x1.5mm legs](https://www.aliexpress.com/item/1005002995402961.html)
- optional - 8mm magnets (2mm height)

## Tools

- Soldering iron. Any iron will work, but I highly recommend something small like TS100 or Pinecil with TS-K tip, it's good for SMD soldering
- Solder, preferably with lead if you can get one. For EU I recommend this [shop](https://botland.store) and Cynel brand. 0.56mm is great for SMD, and you can optionally get 0.9mm for hotswap sockets
- [Flux](https://www.aliexpress.com/item/1005004441105643.html)
- Tweezers (I prefer [reverse](https://www.aliexpress.com/item/1005004188266714.html) instead of regular), pliers, soldering mat, isopropyl alcohol (IPA) and [cotton pads](https://www.aliexpress.com/item/1005003798227116.html) for cleaning

## Build

Start with breaking the combined PCB into two halves using pliers. You can sand down the breaking points or just polish with a sharp knife. Just a bit, small pieces of PCB material are pretty bad for breathing in. Choose left or right half and place it upside down, we'll start from bottom side.

### LEDs

First of all, LEDs can be destroyed with heat, so be careful - use lower temp (something like 300C or lower depending on your solder) and don't hold the iron longer that needed. Second, be careful with placing the LED, they are not symmetrical. One pin (ground) is chamfered, it must be placed on a pad with similar shape (left bottom if you look on it).

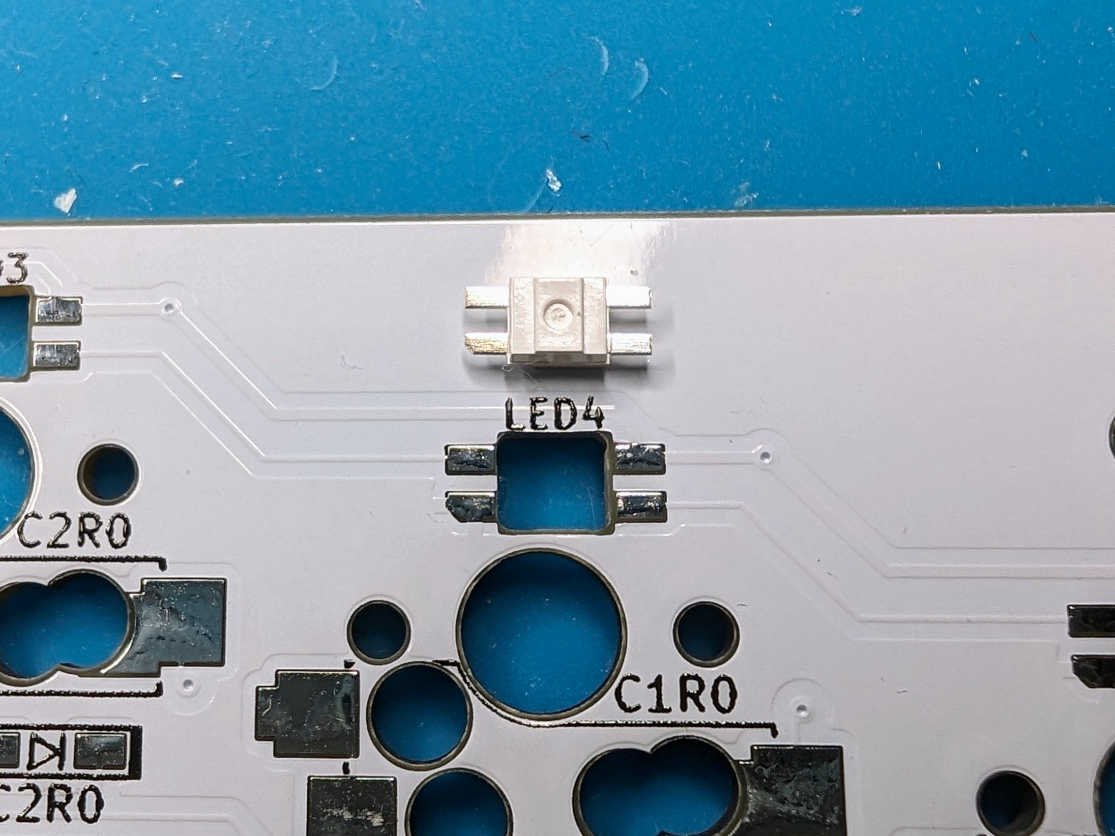
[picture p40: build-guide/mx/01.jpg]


There are several ways of soldering them, my favorite is:

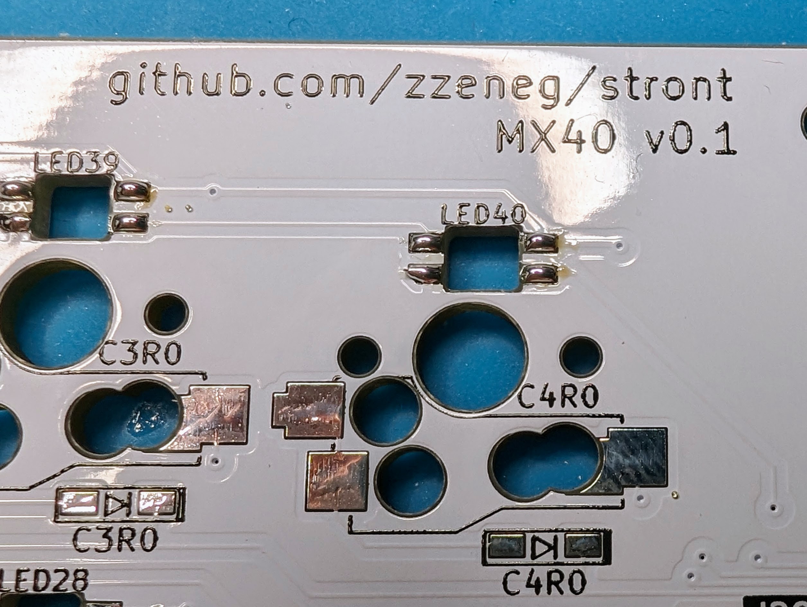
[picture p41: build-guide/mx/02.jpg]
- pre-tin all 4 pads 
- put a LED into place and press it gently with your fingernail or tweezers
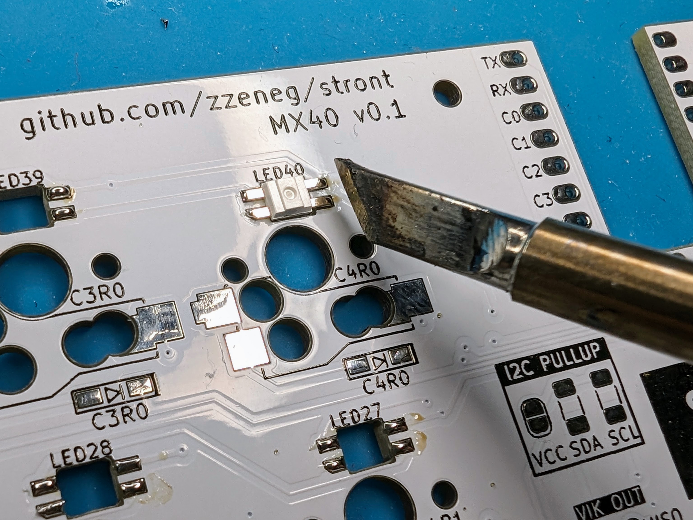
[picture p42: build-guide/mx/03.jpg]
- use TS-K tip to heat two pads and pins at the same time 
- do the same for other two pins
- repeat it for all LEDs

If you don't have a TS-K tip, just do all the pins one by one. The most important thing is to heat pin and pad simultaneously, otherwise you may have cold joints. You can experiment with solder paster and/or flux but I felt like it takes more time without any benefits.

### Diodes

Again, orientation is important. Every diode has a vertical line on it marking the side with cathode, experiment with lighting and angle if you don't see it.

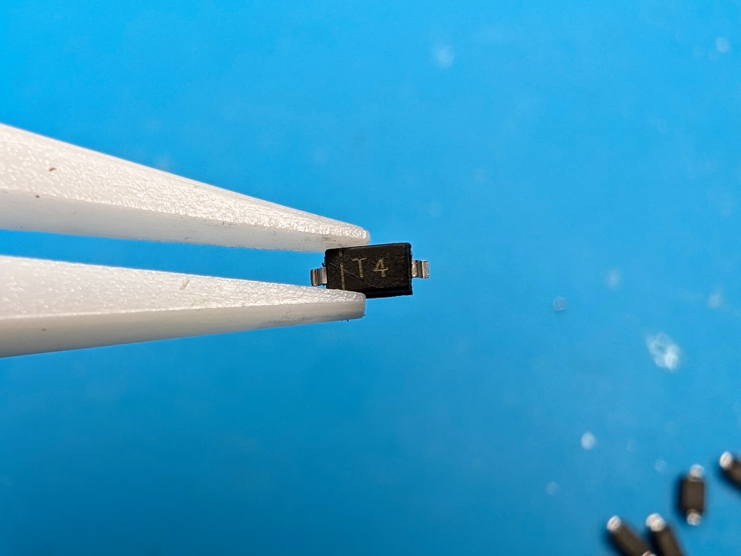
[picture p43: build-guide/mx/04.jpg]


On the PCB cathode is marked with a thick outside line and a vertical line between pads. Here on the photo cathode pad is soldered.

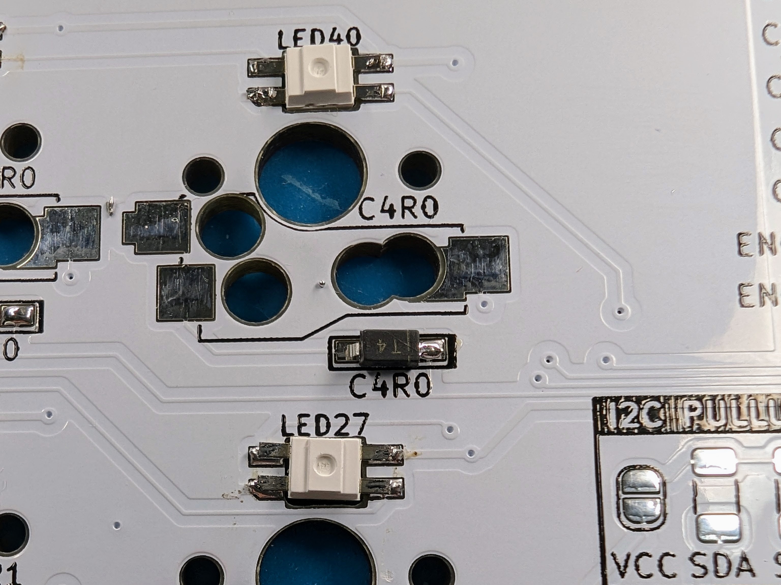
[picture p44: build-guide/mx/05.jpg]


Soldering order:

- tin one pad (doesn't really matter which one, what's important is consistency)
- grab a diode with tweezers and make sure it's oriented correctly
- place it next to the tinned pad, heat the solder blob, put the diode to its place and press it down with fingernail
- solder the second pin by simultaneously heating the pad, pin and solder wire

Repeat it for all diodes, then clean everything with IPA.

### Hotswap sockets

These are also asymmetrical but orientation does not really matter. You can still orient all of them in same way, border lines on PCB should help with that. If you have thick solder wire - use it, you'd need much more solder here compared to LEDs/diodes. Soldering process is the same as for diodes - pre-tin one side, put the socket, heat solder and push it into place. Solder second pin, repeat for all others.

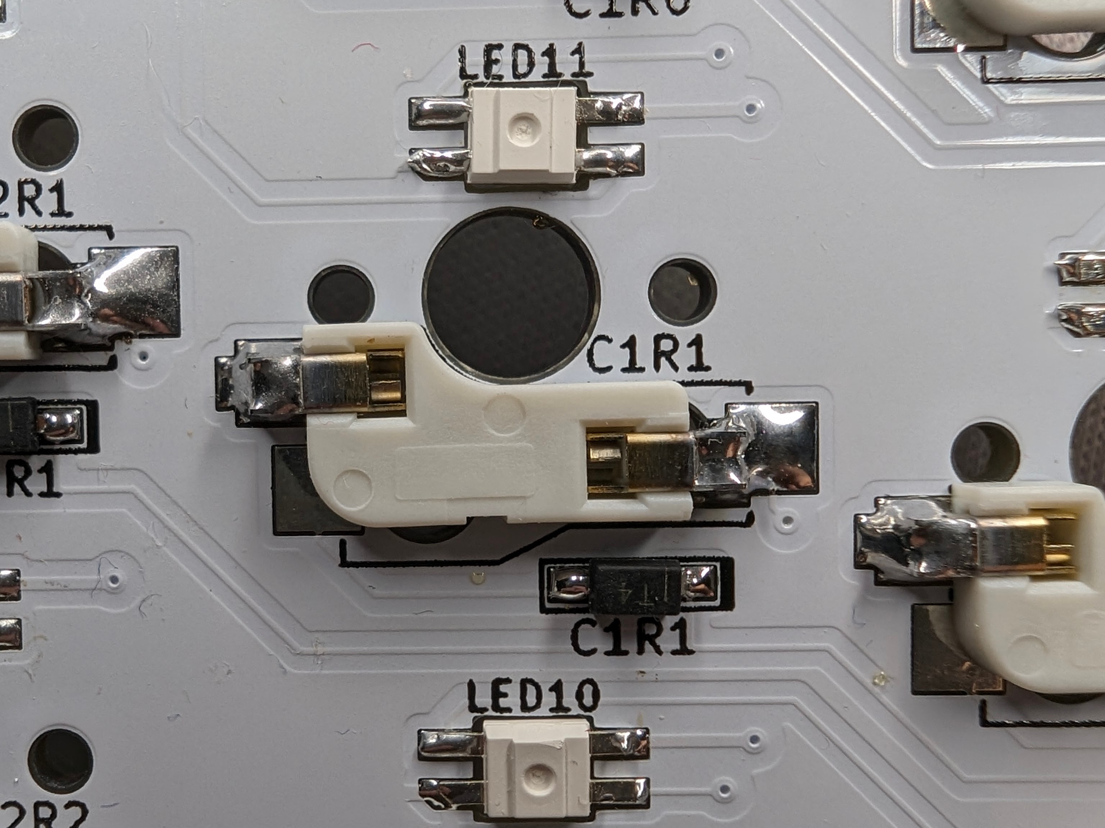
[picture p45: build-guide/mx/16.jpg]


Clean it with IPA, it's a bit harder with sockets but do your best.

### MCU

We're done with bottom side, so **FLIP THE PCB**. MCU goes on top side, so triple check it, you really-really don't want to solder it on the bottom side (I did it once so I know what I'm talking about). Also, I recommend to flash the MCU before soldering, I didn't see a dead one yet but you never know. Connect it to the computer and put a precompiled firmware file into a disk that would appear.

Soldering process:

- pre-tin one (any) pad
- place the MCU on pads, heat the pre-tinned pad and move MCU into correct place (all holes must match), you can use pinhead/socket row to align it
- solder a pad on the opposite side of the MCU to hold it in place
- go through all pads one by one and solder them
- double check everything, it may be tricky to solder the PCB's pads sometimes but it's easy to spot it

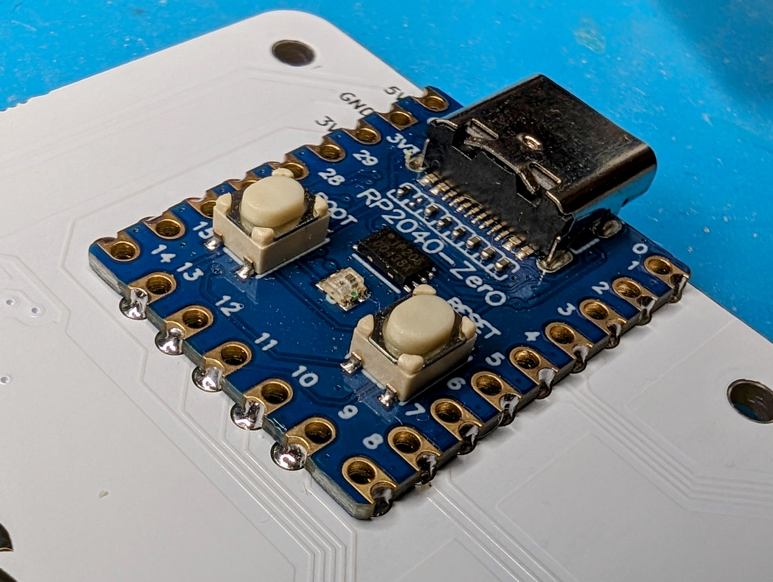
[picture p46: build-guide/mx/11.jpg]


### USB-C connector

> [!CAUTION]
> Do not connect that USB-C to PC, it's only for interconnect between left and right sides

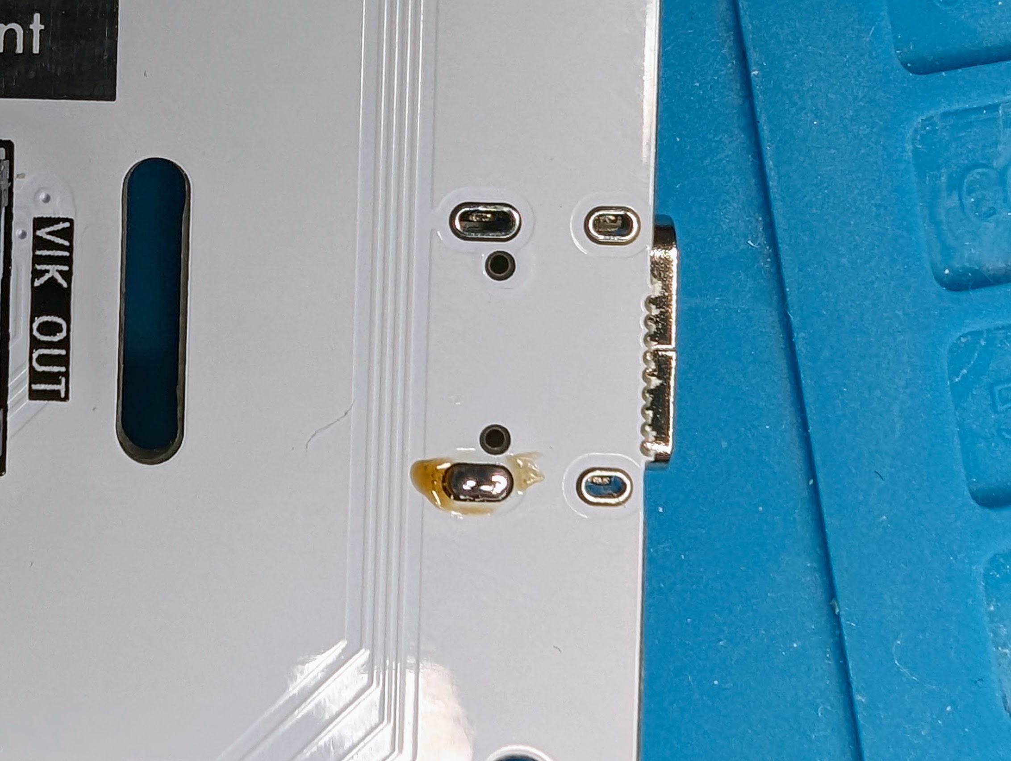
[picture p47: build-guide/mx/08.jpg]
- insert the connector into holes and solder one leg from the bottom side (just to hold it in place) 
- put flux on pads, add small amounts of solder and carefully heat each pin one by one heat the pads and solder paste.
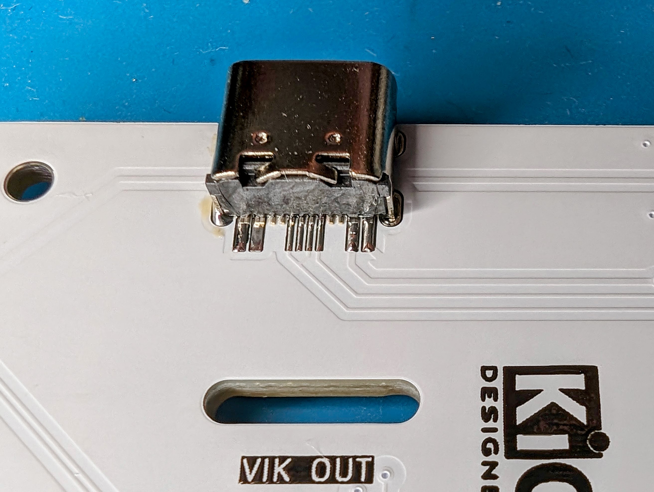
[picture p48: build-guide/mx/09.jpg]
- if some pins are shorted - add flux and move tip from the connector to outside and remove extra solder 
- when pads are done, solder other legs from bottom side, add more solder to make sure it's firmly soldered but remove extras afterwards (solder must be flat with PCB, no blobs)
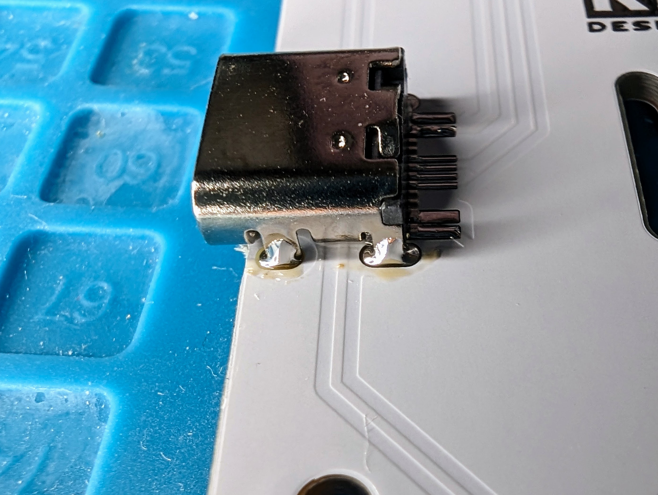
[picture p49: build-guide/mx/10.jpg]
- I recommend to solder legs on top side as well 

### TRRS connector - MX38 version only ⚠️

You can solder TRRS connector if you want, remember to always disconnect power before unplugging it. It's super easy, so no photos.

### Second half - repeat all previous steps

### Roller/rotary encoders

Choose your encoders and solder them, there's only one way to solder it. I prefer to cut pins before soldering to get small pretty solder blobs.

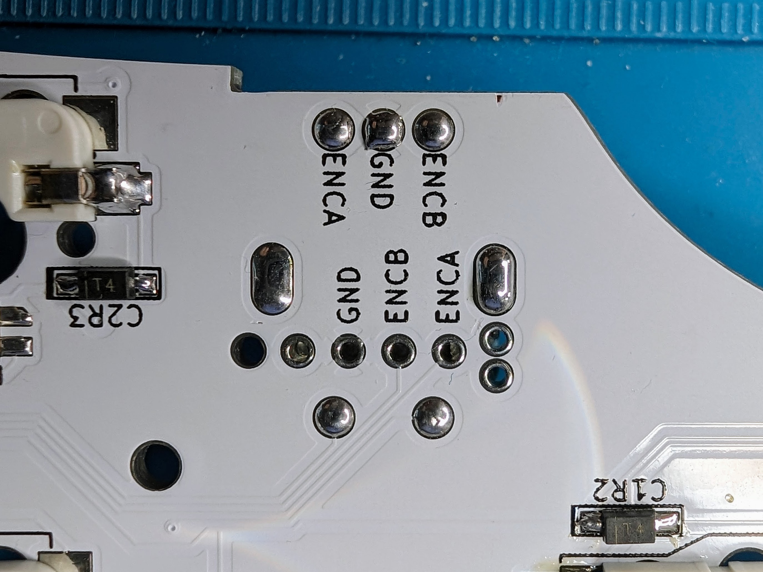
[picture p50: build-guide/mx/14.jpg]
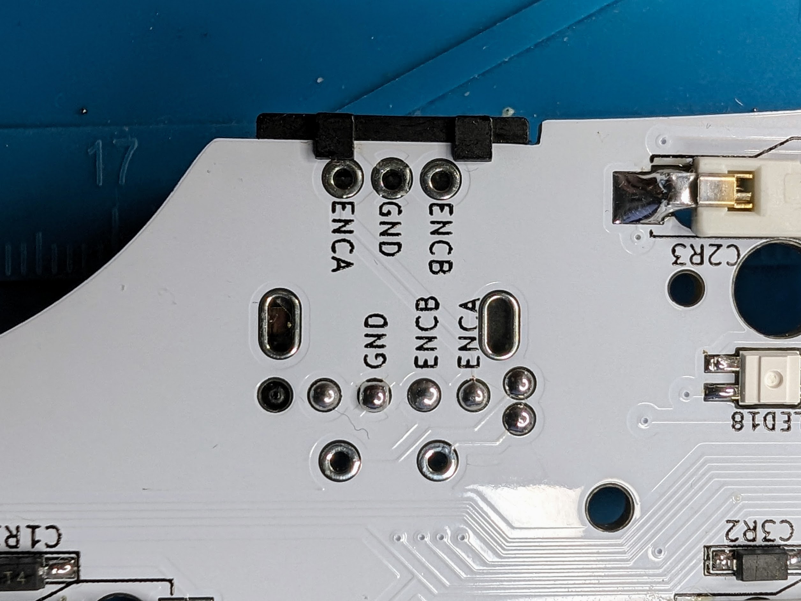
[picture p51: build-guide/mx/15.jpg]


### Vertical FFC connector (VIK/Cirque/Bare display)

> Skip this if using Azoteq without VIK adapter. Solder wires directly from Azoteq to testing pads on the PCB (VCC/GND/SDA/SCL).

Pretty similar to USB-C connector but easier thanks to 1mm space between pins. Also if you fail the step you can use a [daughterboard](https://www.aliexpress.com/item/4001156449357.html) (0.5mm pitch, 12 pins), it matches the holes on the PCB.

- align connector to silkscreen - black moving part should be on the right (if you messed up here, don't worry and just use another cable during assembly)
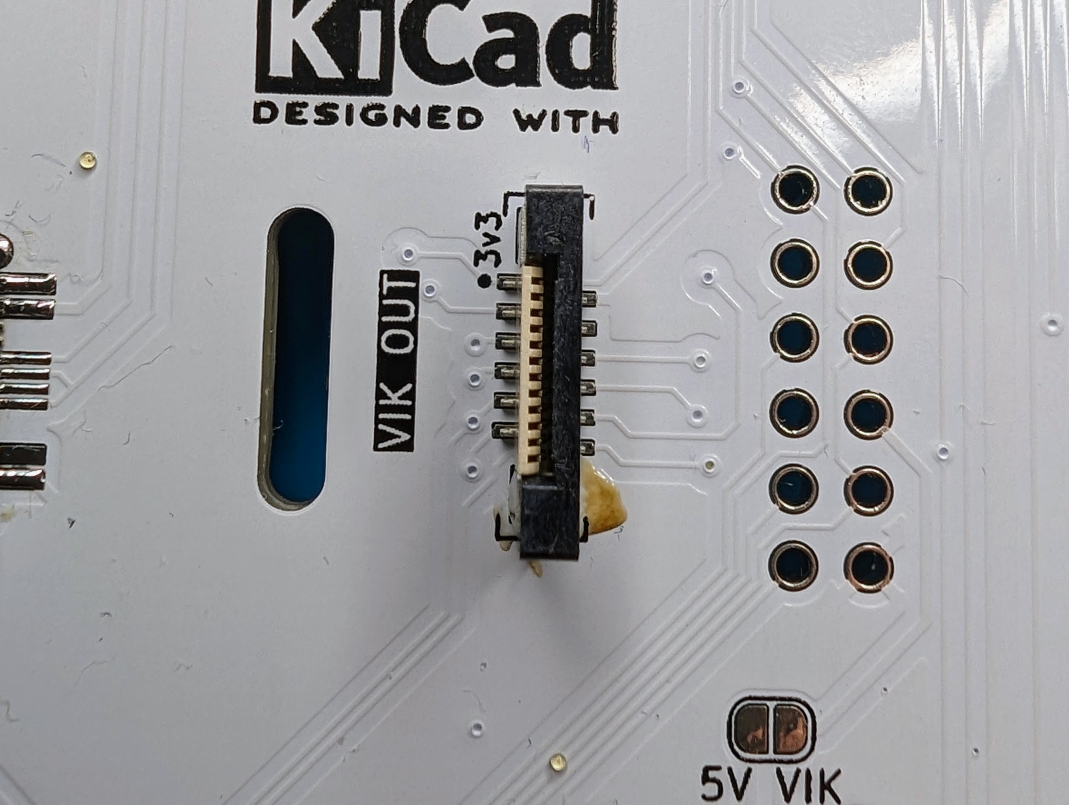
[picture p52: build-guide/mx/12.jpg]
- tin one square mounting pad, align small pins to pads and solder big pad 
- carefully solder pins one by one
- make sure there are no bridges and solder the second mounting pad
- you can desolder and restart in case of shorts or bad placement, but be careful not to lift pads - move the connector horizontally, not vertically

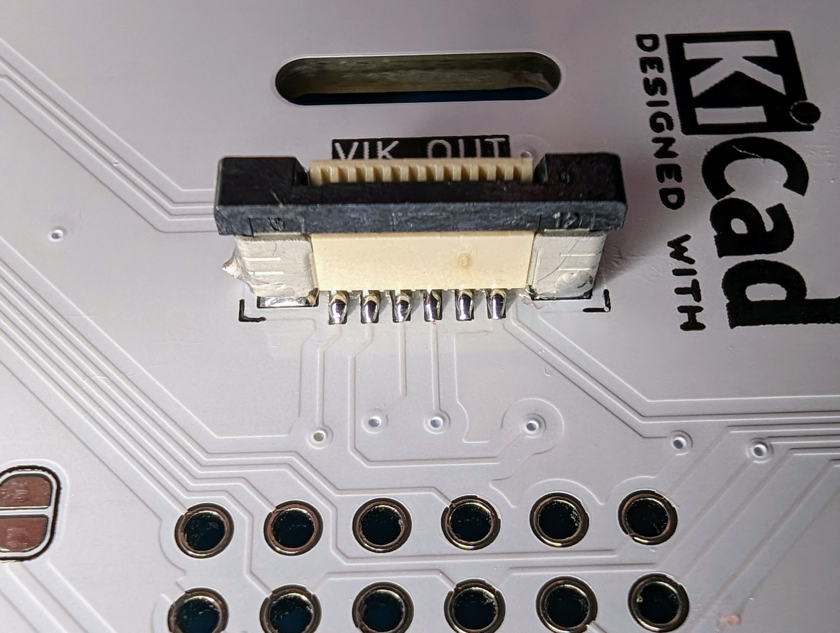
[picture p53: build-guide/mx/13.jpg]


### Display

> Skip this if using VIK for the display. Assemble the [adapter](https://github.com/zzeneg/vik-display-adapter) instead.

Start with adding male connector to the PCB.

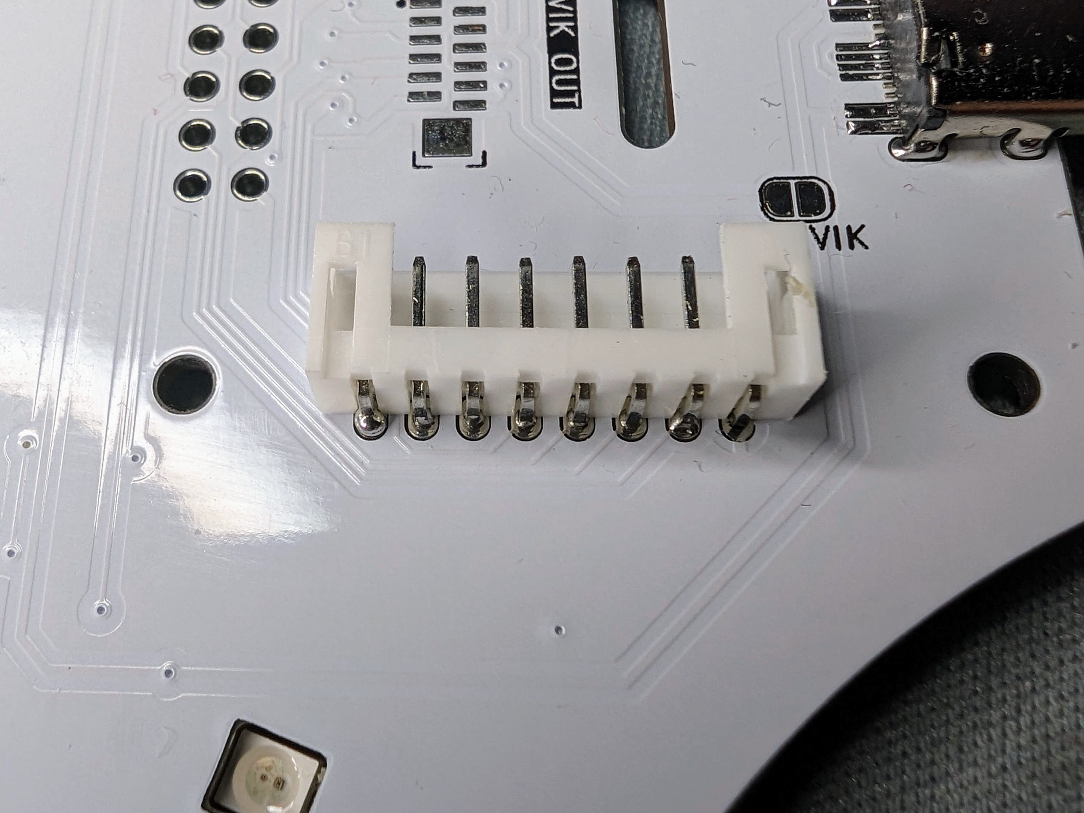
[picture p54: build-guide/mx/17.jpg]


Take a female connector with wires and cut them to 5cm. Make sure the connector is correctly oriented (when inserted into PCB the display should be facing up) and solder them. Cut wires/solder blobs on top afterwards so that display's PCB is flat. You can hot glue wires to display to secure them in place.

### Testing/flashing

At this point you can connect everything and test the keyboard. Again, be extra careful with USB-C ports.

- grab default [pre-compiled firmware](./../firmware/qmk/stront_default.uf2)
- connect one side to PC and go into bootloader by double pressing reset button
- copy the file onto the disk that would appear
- repeat for second half
- firmware has [EE_HANDS](https://docs.qmk.fm/#/feature_split_keyboard?id=handedness-by-eeprom) enabled so any side can be master. You'd have to specify left or right side by pressing key combinations - hold inner thumb key, then hold outer thumb key to activate SYSTEM layer. Now press outer bottom pinky key for left side or inner bottom index key for right side (insert switches into those places). E.g.

  - if your left side is detected as right side, do this:

  

  - if your right side is detected as left side, do this:

  

  See [keymap](https://github.com/zzeneg/qmk_firmware/blob/feature/stront/keyboards/stront/keymaps/default/keymap.c) for better understanding. **Reconnect the keyboard to apply changes.**

- test display and touchpad
- test all keys - insert switches or short sockets with something like metal tweezers or TRRS cable
- test encoders
- test USB-C interconnect in all 4 possible cable positions
- test LEDs - press or lightly tap each LED with your fingers to make sure the soldering is fine, there should be no flickering
- in case of any issues go to troubleshooting section

### Assembly

- add heatset inserts into covers
  - for Nylon/PLA use 3.5mm diameter and insert them with soldering iron or special heat gun
  - for resin use 3.2mm diameter and super glue. DO NOT apply heat to resin case! If the hole is too small, just drill it to the correct size
- insert modules (display/touchpads) into covers, secure them in place with hot glue on the inside
- insert PCB into case. Inserting USB-C/TRRS connectors will require just a bit of force
- connect FFC and display cables, check continuity (or examine 3v3 label visually), try forward/reverse FFC cables if needed. FFC cables can be bent as needed.
- flash correct firmware for each side, test that display and touchpad are working
- insert 5 nuts into bottom case
- attach bottom case with 14mm and 6mm/8mm screws. If the 8mm screws for MX seem too short, try to tighten the hex with a long screw first.
- add legs and magnets if needed
- add switches and knobs

Examples:

- round display
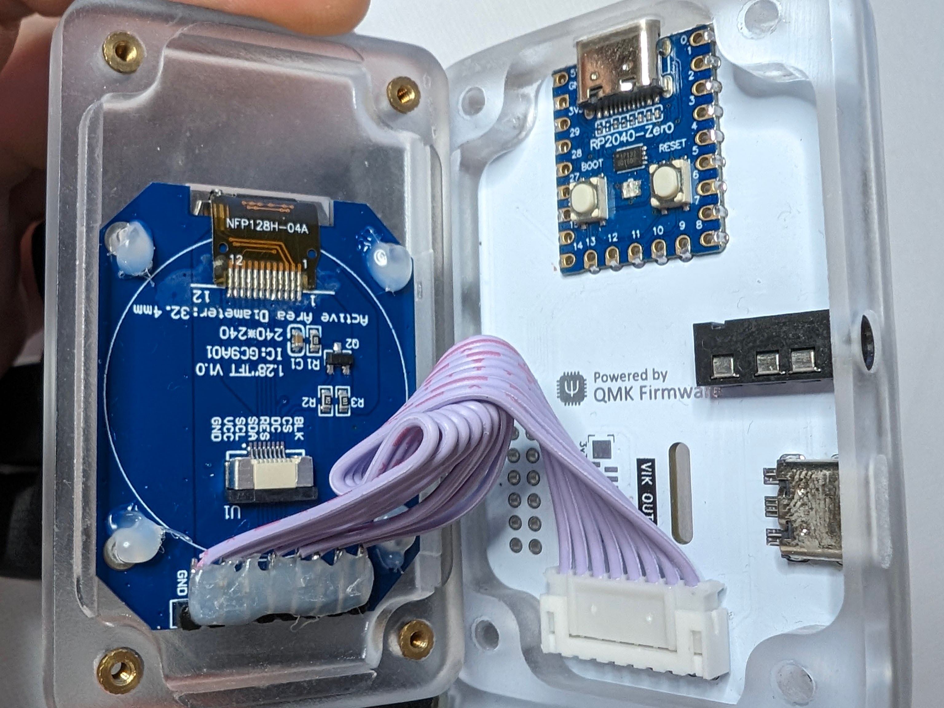
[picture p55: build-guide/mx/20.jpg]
  
- bare display with adapter
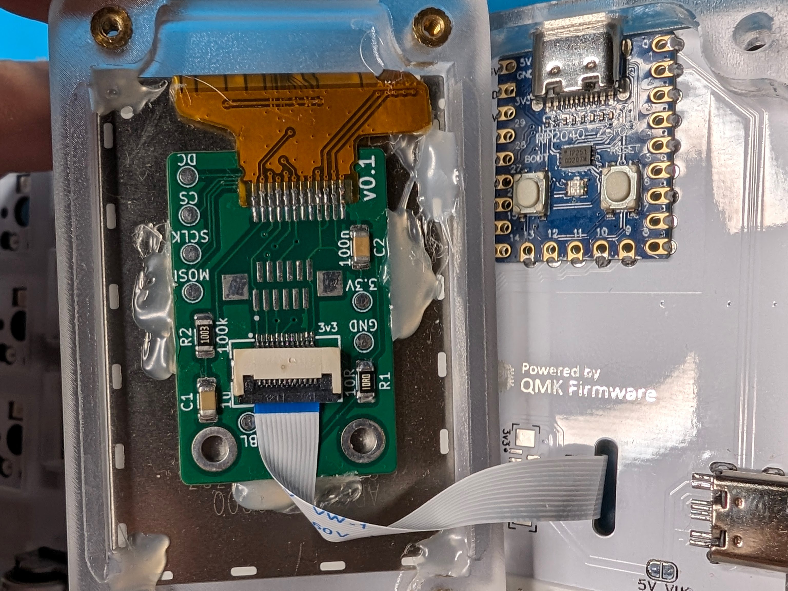
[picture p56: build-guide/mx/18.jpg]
  
- Azoteq with adapter
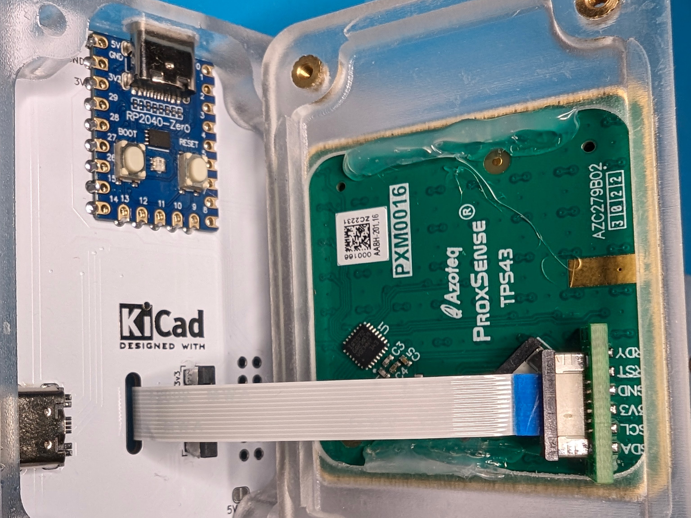
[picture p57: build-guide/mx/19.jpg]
  

### Troubleshooting

See https://github.com/zzeneg/stront/tree/main/build-guide/choc#troubleshooting

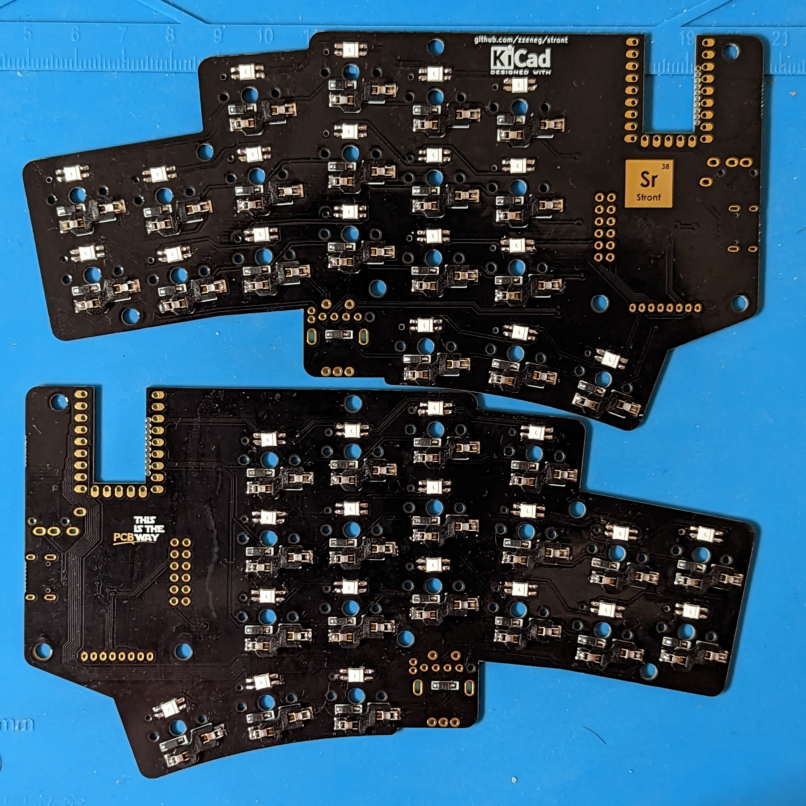
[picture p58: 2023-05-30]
build-guide/choc/06.jpg

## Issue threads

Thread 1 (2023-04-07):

54 key (or more version)

BorjaLL, 2023-04-07:
This looks amazing! I'd love a version with more keys for my use cases. How hard would that be to iterate ?

zzeneg, 2023-04-10:
So the main problem is the number of IO pins on the MCU, I'm already using all of them - the LCD display requires quite a lot. For 54+ keys we'd need 2-3 extra pins, and I think the optimal solution would be to replace the MCU with something bigger, in the form factor of original Pi Pico, for example Waveshare RP2040 Plus. It has 6 more IO pins which is more than enough, it's much bigger but given the extra row it should be ok. The total cost will increase but not by much.
Of course these changes will require complete rework of the keyboard and unfortunately I'm not interested in so many keys, so I would not create such version by myself. But I welcome any attempt to fork Stront and create a bigger version (or just make it as a new keyboard).

Zilvertail, 2023-05-13:
Couldn't you drop the rotary encoders and get more keys that way? Then map the rotary functions onto the trackpad perhaps?

zzeneg, 2023-05-14:
Yes, it's a valid alternative, you can drop them and get 30 keys per side. Not sure about using trackpad as a replacement, probably it's possible but will need a lot code.
I considered this, but I thought that given the there will be an additional row, you can just put a bigger MCU anyway.

Zilvertail, 2023-05-14:
Yeah, my point was to get more STRONT's out into the wild without limiting to many people, i really like the qmk-hid-host you wrote to handle the keyboard, and would love for more to adopt that, and getting more keys easily onto the STRONT would help develop the chances of a broader adaptation :)

zzeneg, 2024-01-22:
So if anyone looks for an open-sources 54-key alternative with display and touchpad I'd recommend Dilemma MAX (4x6+3) offered by @Bastardkb - https://github.com/Bastardkb/Dilemma

zzeneg, 2024-01-22:
So if anyone looks for an open-sources 54-key alternative with display and touchpad I'd recommend Dilemma MAX (4x6+3) offered by @Bastardkb - https://github.com/Bastardkb/Dilemma. There is no build guide or case for the displays at the moment but the PCB itself supports it.

Closed 2024-01-22.

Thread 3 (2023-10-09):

Unfound file

sedghi, 2023-10-09:
This link does not work

https://github.com/zzeneg/stront/blob/main/gerbers/mx/pcb.zip

zzeneg, 2023-10-11:
Fixed, thank you!

Closed 2023-10-11.

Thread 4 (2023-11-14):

Cirque trackpad won't work

TildeWill, 2023-11-14:
I just built a ChocV Stront. Lights, keys, square display, and rotary encoder all work fine. I've got the trackpad on the right side, using the precompiled firmware,  using OSX (not Windows) and I can't get the track pad to move the mouse. Is there something extra I'm missing like installing a driver? Solder a jumper that wasn't mentioned? Thanks!

zzeneg, 2023-11-14:
- did you check that the trackpad is connected correctly? e.g. VCC/GND on trackpad (there are testing pads on the bottom) have continuity to VCC/GND on the MCU?
- do you use trackpad in SPI (default) mode?
- which firmware exactly did you use?

TildeWill, 2023-11-20:
Thanks zzeneg!
1) I've attached a photo to make sure I understand you. Are the "testing pads" what I've circled in the photo? If so, I've got continuity for most pins, but nothing when I probe RES and BL from the testing pads.
2) Yes, there's a resistor in R1 on the trackpad, so it should be SPI from what I read in the datasheet. I'm using a 40mm flat trackpad.
3) I used the file `firmware/qmk/stront_zzeneg-rect-flat.uf2`
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

zzeneg, 2023-11-20:
No, I meant pads on the cirque itself:
https://github.com/zzeneg/stront/blob/main/build-guide/choc/17.jpg
Connect trackpad to keyboard and test continuity between testing pads and MCU - first GND and VCC to verify that cable is correctly oriented and inserted, then pin 9 to SS, 10 to SCK, 11 to SI, 12 to SO (I'm not 100% sure on this mapping but just make that pin is connected to some pad 😄).

TildeWill, 2023-11-21:
Ah, yes, the pads on the cirque make sense. I assume the BTN1, BTN2, and BTN3 aren't wired to anything?

Otherwise it looks like I have problems:
1. DR and SS on the Cirque both got to pin 9 on the MCU
2. SDA and SCK on the Cirque both go to pin 10 on the MCU
3. SI and SCL on the Cirque both got to pin 11 on the MCU

zzeneg, 2023-11-21:
2 and 3 are ok, this is how it should be (to support both SPI and I2C modes). However, I don't think that SS should be connected to DR so it may be the problem. I think you have shorted them underneath the FPC vertical connector (second from top pins on both sides). Try to clean/reflow them maybe?

TildeWill, 2023-12-13:
For any future visitors, I removed the line below from `keyboards/stront/config.h` because my trackpad was now oriented a different direction:
```c++
#define POINTING_DEVICE_ROTATION_180
```

Closed 2023-11-27.

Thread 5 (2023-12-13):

Breakout the reset button

TildeWill, 2023-12-13:
Now that the case is all screwed on I want to update my firmware and try out different configurations, but the reset button is not accessible. I'd love to see a rev of the board and case that breaks out the reset button so I can flash new firmware without taking the case off.

zzeneg, 2023-12-14:
It's not possible to breakout reset button on RP2040 Zero, unfortunately. Use bootloader key in keymap + bootmagic, default firmware has them.

TildeWill, 2023-12-14:
Nice, that's what I needed 👍

Closed 2023-12-14.

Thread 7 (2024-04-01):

stront40 firmware

tangbonze, 2024-04-01:
Hi There:
First I want to say Thank you for create stront. It is really amazing.
I notice you have create new stront40. I can't wait to try it.
May I ask do you have plan to release firmware or it just same as stront?
Thanks.

zzeneg, 2024-04-01:
Hey! Thanks for following my work :) stront40 is work in progress, I created and ordered it but did not assemble and test it yet. There's no firmware, it will be just a bit different from regular stront.
I should be able to properly test PCB and firmware in a week or two but the case will take longer.

tangbonze, 2024-04-02:
thank you. I will wait for your release.

Closed 2024-04-02.

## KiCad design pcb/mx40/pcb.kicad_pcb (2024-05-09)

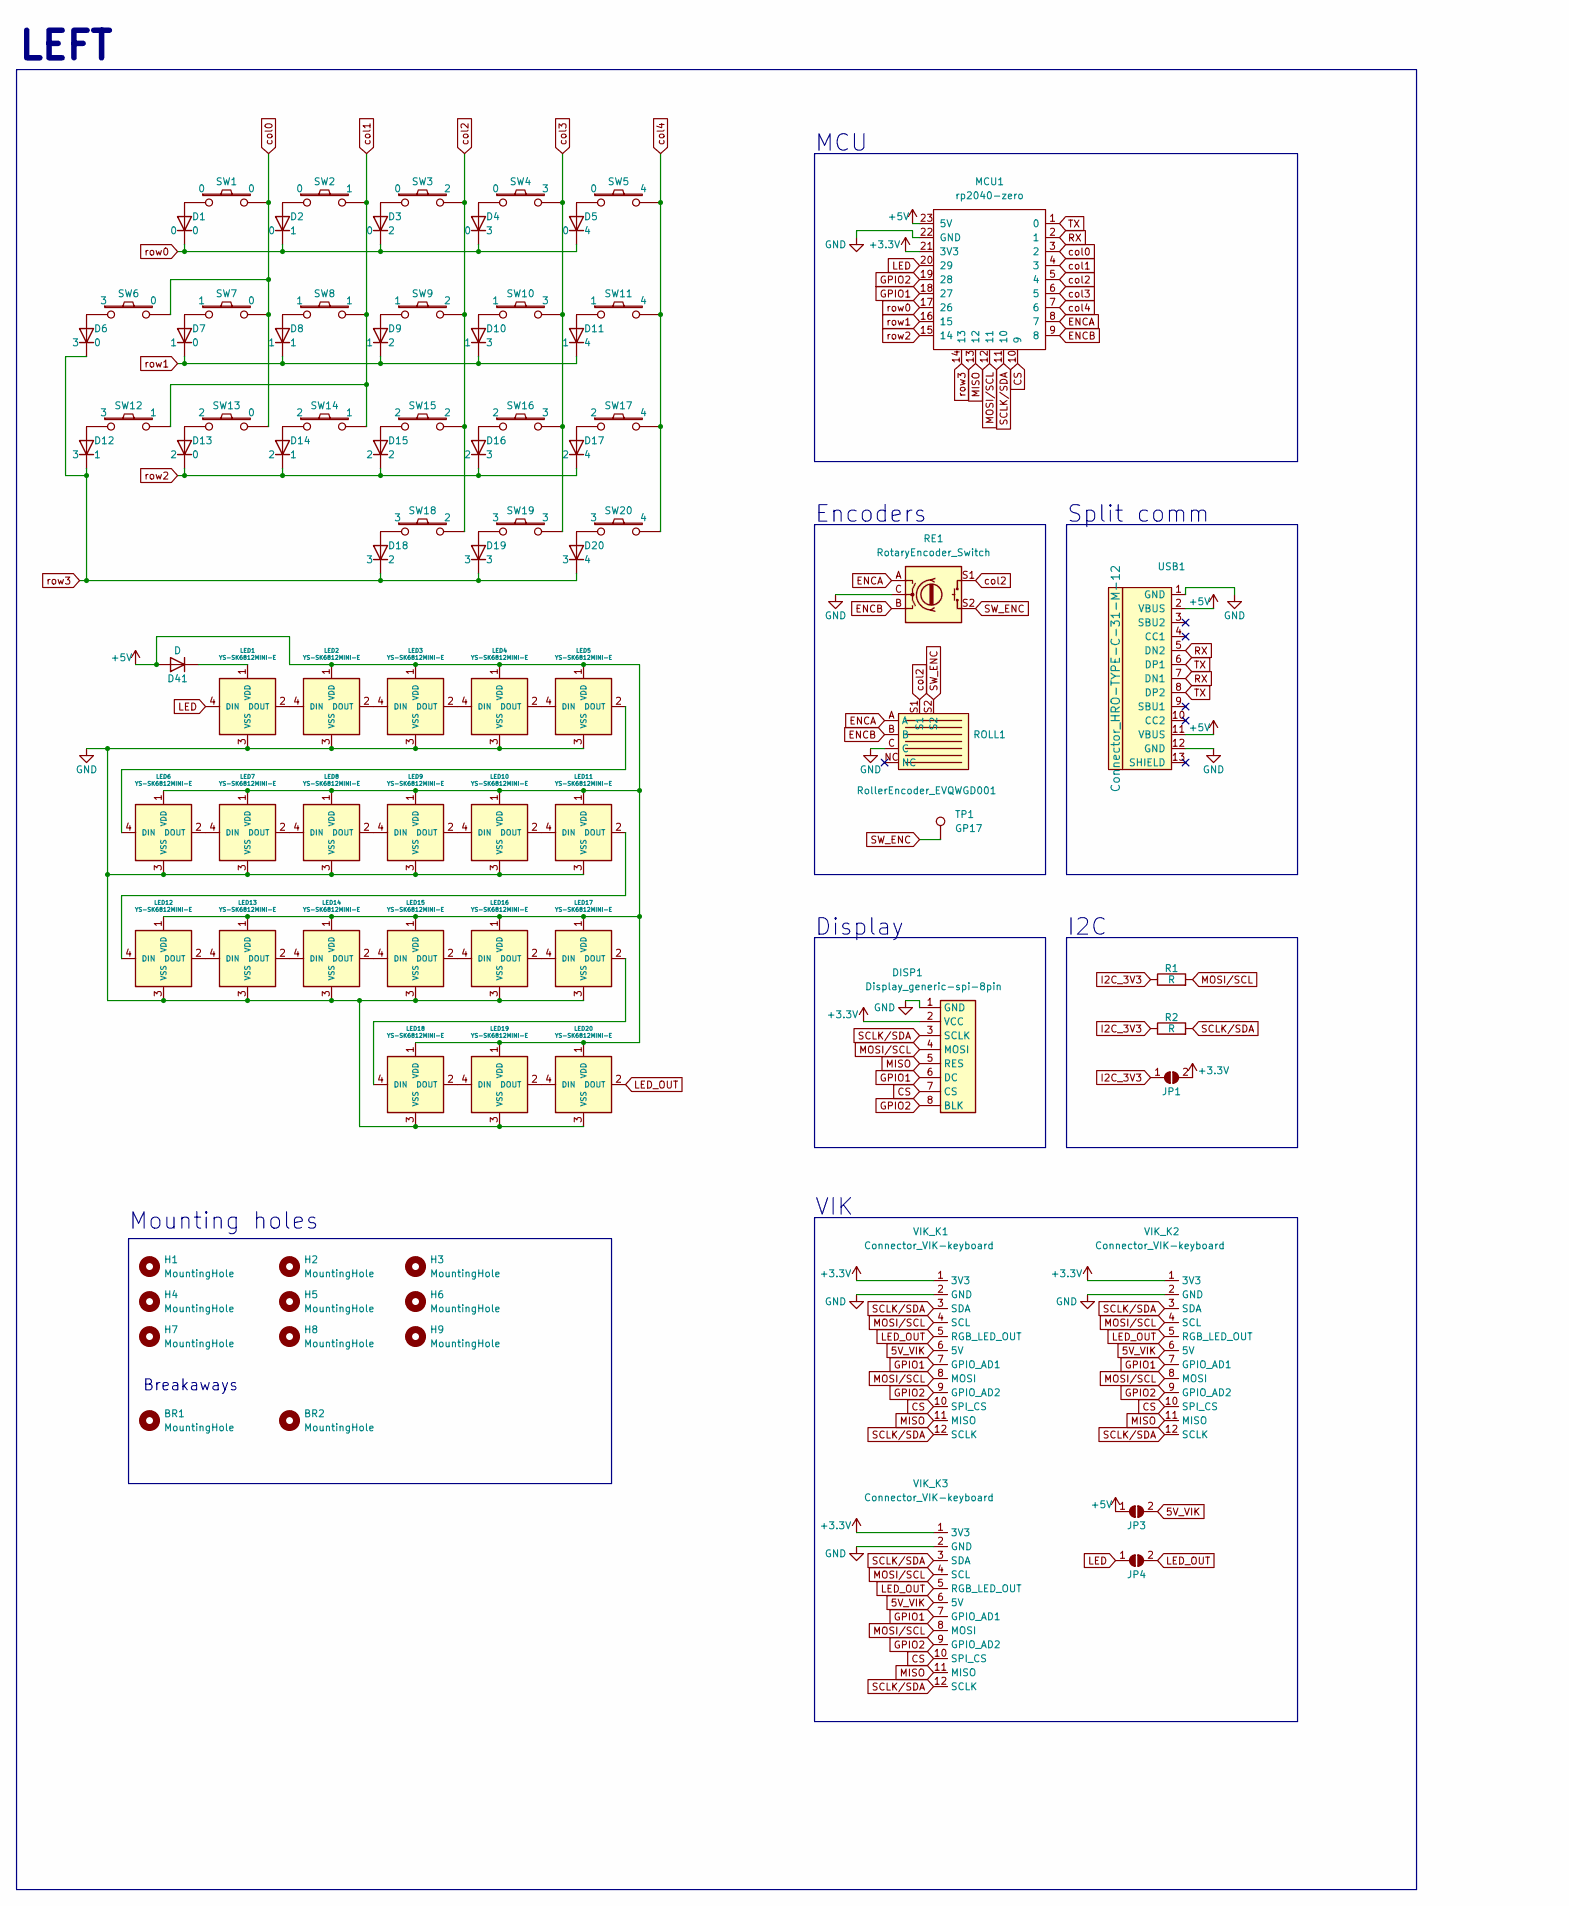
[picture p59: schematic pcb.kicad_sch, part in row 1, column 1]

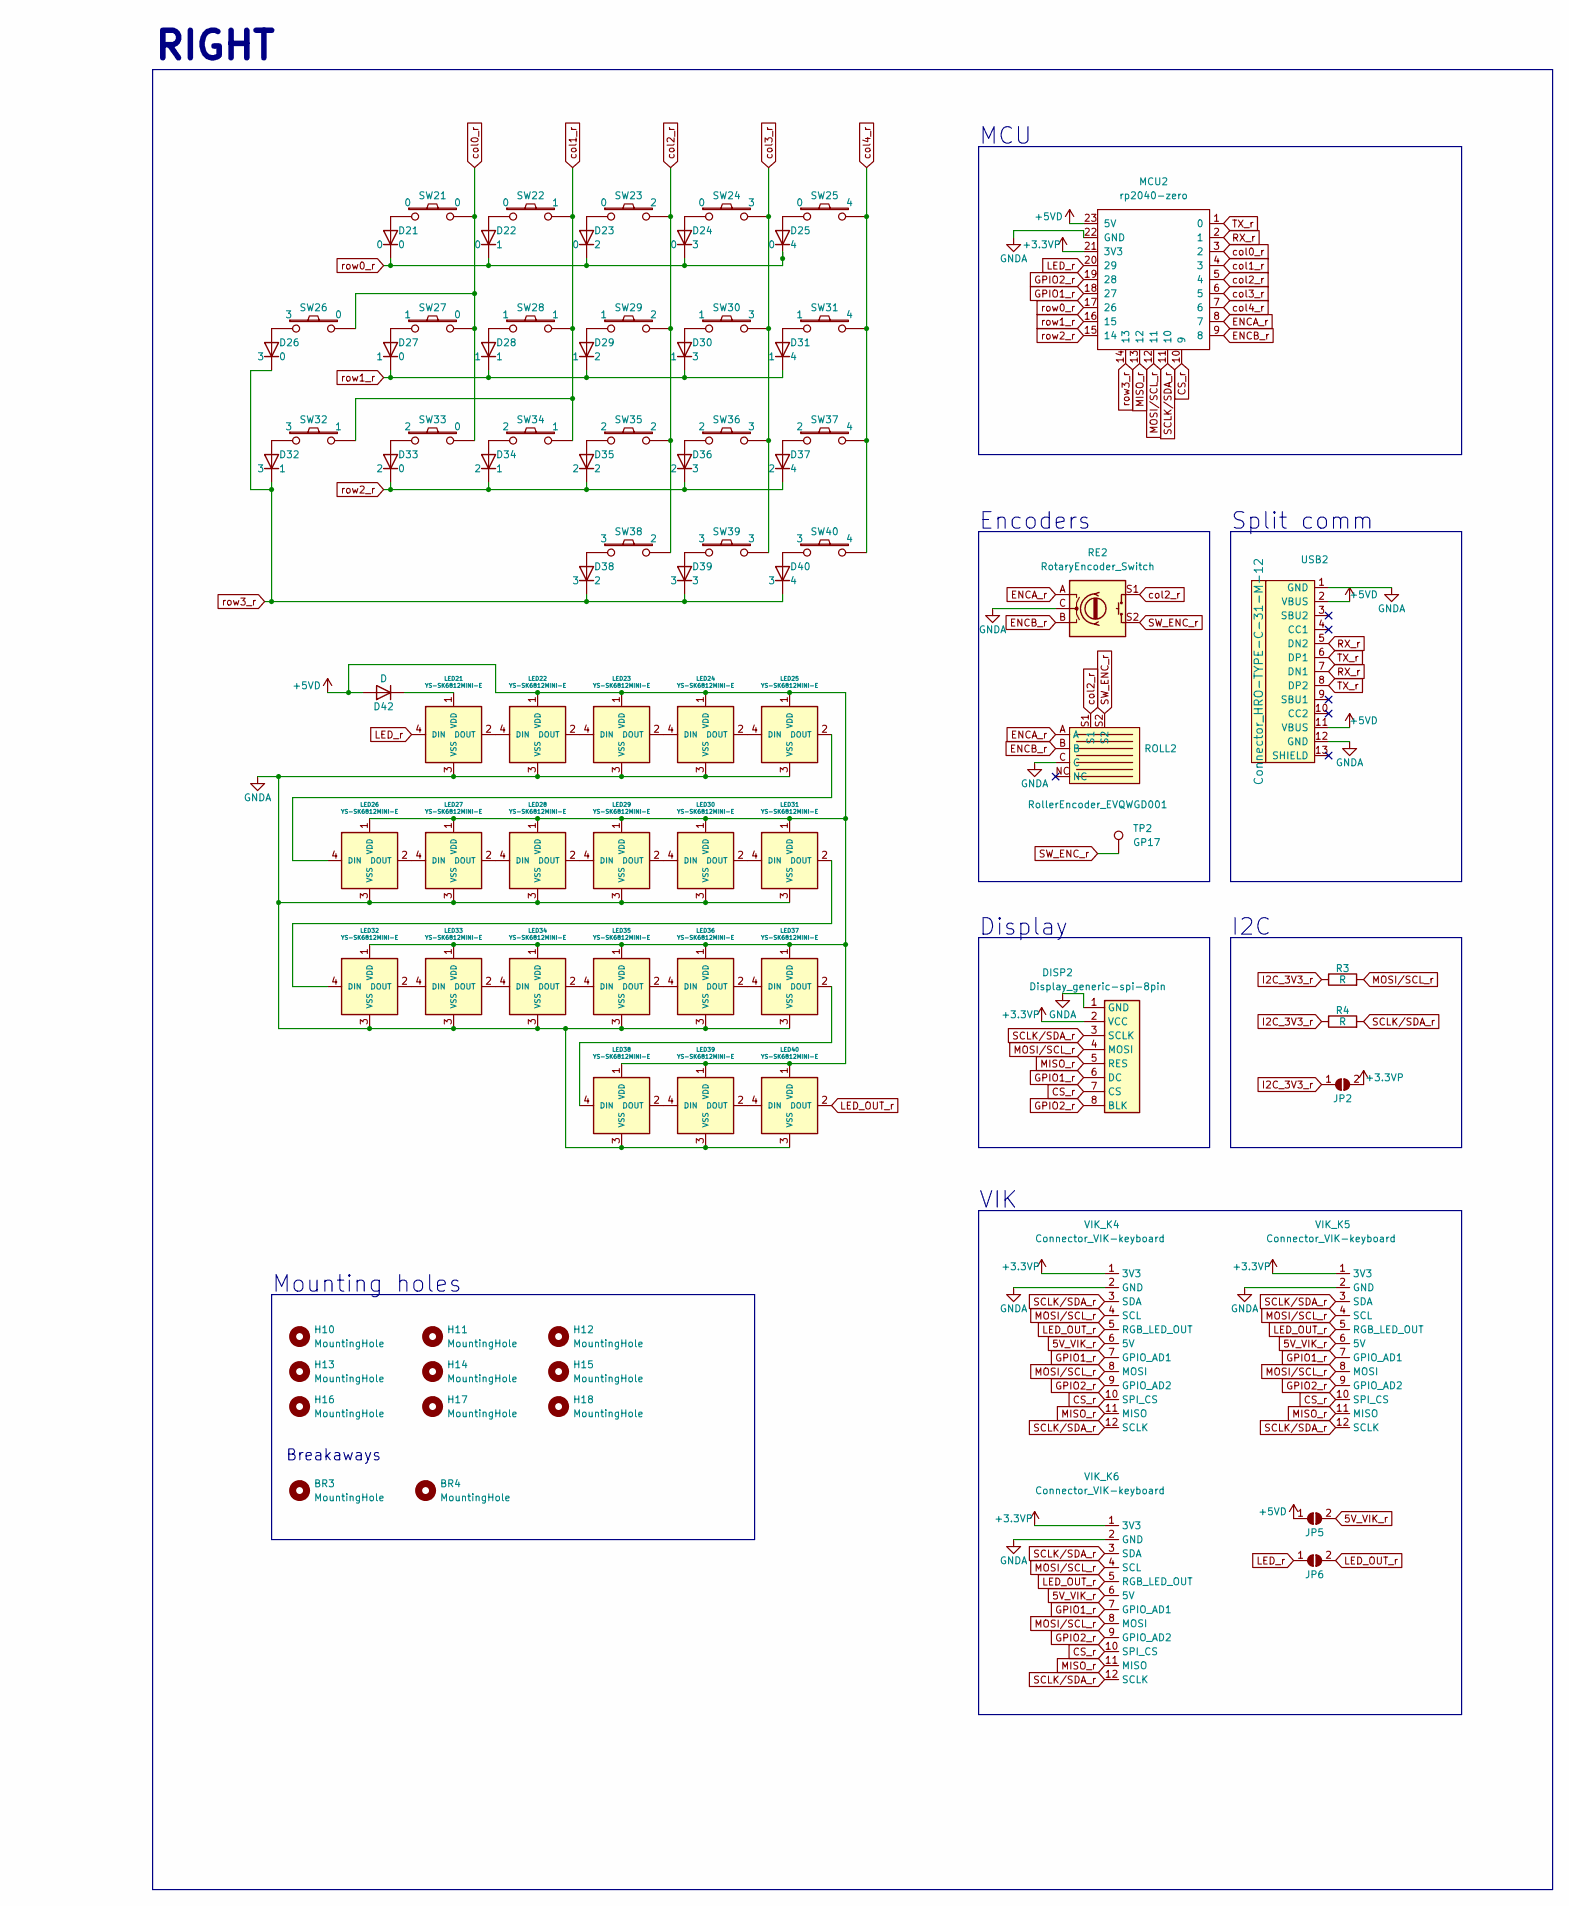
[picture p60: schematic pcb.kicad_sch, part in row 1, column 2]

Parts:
BR1, BR2, BR3, BR4: MountingHole; Hole_Breakaway-Tabs
D1, D2, D3, D4, D5, D6, D7, D8, D9, D10, D11, D12, D13, D14, D15, D16, D17, D18, D19, D20, D21, D22, D23, D24, D25, D26, D27, D28, D29, D30, D31, D32, D33, D34, D35, D36, D37, D38, D39, D40, D41, D42: D; Diode_1N4148-SOD123
DISP1, DISP2: Display_generic-spi-8pin; Connector_Display-8pin-SPI-2.0mm
H1, H2, H3, H4, H5, H6, H7, H8, H9, H10, H11, H12, H13, H14, H15, H16, H17, H18: MountingHole; Hole_M2
JP1, JP2, JP3, JP4, JP5, JP6: SolderJumper_2_Open; SolderJumper-2_P1.3mm_Open_RoundedPad1.0x1.5mm
LED1, LED2, LED3, LED4, LED5, LED6, LED7, LED8, LED9, LED10, LED11, LED12, LED13, LED14, LED15, LED16, LED17, LED18, LED19, LED20, LED21, LED22, LED23, LED24, LED25, LED26, LED27, LED28, LED29, LED30, LED31, LED32, LED33, LED34, LED35, LED36, LED37, LED38, LED39, LED40: YS-SK6812MINI-E; LED_SK6812-MINI-E
MCU1, MCU2: rp2040-zero; MCU_rp2040-zero-tht
R1, R2, R3, R4: R; R_1206_3216Metric
RE1, RE2: RotaryEncoder_Switch; RotaryEncoder_EC11
ROLL1, ROLL2: RollerEncoder_EVQWGD001; RotaryEncoder_EVQWGD001
SW1, SW2, SW3, SW4, SW5, SW6, SW7, SW8, SW9, SW10, SW11, SW12, SW13, SW14, SW15, SW16, SW17, SW18, SW19, SW20, SW21, SW22, SW23, SW24, SW25, SW26, SW27, SW28, SW29, SW30, SW31, SW32, SW33, SW34, SW35, SW36, SW37, SW38, SW39, SW40: Switch; Switch_MXKS-hotswap-south
TP1, TP2: GP17; TestPoint_Pad_D1.5mm
USB1, USB2: Connector_HRO-TYPE-C-31-M-12; Connector_HRO-TYPE-C-31-M-12-data
VIK_K1, VIK_K4: Connector_VIK-keyboard; Connector_VIK-vertical-keyboard
VIK_K2, VIK_K5: Connector_VIK-keyboard; vik-keyboard-throughole
VIK_K3, VIK_K6: Connector_VIK-keyboard; vik-keyboard-connector-horizontal

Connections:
5V_VIK: JP3.2 (B), VIK_K1.6 (5V), VIK_K2.6 (5V), VIK_K3.6 (5V)
5V_VIK_r: JP5.2 (B), VIK_K4.6 (5V), VIK_K5.6 (5V), VIK_K6.6 (5V)
+3.3V: DISP1.2 (VCC), JP1.2 (B), MCU1.21 (3V3), VIK_K1.1 (3V3), VIK_K2.1 (3V3), VIK_K3.1 (3V3)
+3.3VP: DISP2.2 (VCC), JP2.2 (B), MCU2.21 (3V3), VIK_K4.1 (3V3), VIK_K5.1 (3V3), VIK_K6.1 (3V3)
+5V: D41.2 (A), JP3.1 (A), LED2.1 (VDD), LED3.1 (VDD), LED4.1 (VDD), LED5.1 (VDD), LED6.1 (VDD), LED7.1 (VDD), LED8.1 (VDD), LED9.1 (VDD), LED10.1 (VDD), LED11.1 (VDD), LED12.1 (VDD), LED13.1 (VDD), LED14.1 (VDD), LED15.1 (VDD), LED16.1 (VDD), LED17.1 (VDD), LED18.1 (VDD), LED19.1 (VDD), LED20.1 (VDD), MCU1.23 (5V), USB1.2 (VBUS), USB1.11 (VBUS)
+5VD: D42.2 (A), JP5.1 (A), LED22.1 (VDD), LED23.1 (VDD), LED24.1 (VDD), LED25.1 (VDD), LED26.1 (VDD), LED27.1 (VDD), LED28.1 (VDD), LED29.1 (VDD), LED30.1 (VDD), LED31.1 (VDD), LED32.1 (VDD), LED33.1 (VDD), LED34.1 (VDD), LED35.1 (VDD), LED36.1 (VDD), LED37.1 (VDD), LED38.1 (VDD), LED39.1 (VDD), LED40.1 (VDD), MCU2.23 (5V), USB2.2 (VBUS), USB2.11 (VBUS)
CS: DISP1.7 (CS), MCU1.10 (9), VIK_K1.10 (SPI_CS), VIK_K2.10 (SPI_CS), VIK_K3.10 (SPI_CS)
CS_r: DISP2.7 (CS), MCU2.10 (9), VIK_K4.10 (SPI_CS), VIK_K5.10 (SPI_CS), VIK_K6.10 (SPI_CS)
ENCA: MCU1.8 (7), RE1.A, ROLL1.A
ENCA_r: MCU2.8 (7), RE2.A, ROLL2.A
ENCB: MCU1.9 (8), RE1.B, ROLL1.B
ENCB_r: MCU2.9 (8), RE2.B, ROLL2.B
GND: DISP1.1 (GND), LED1.3 (VSS), LED2.3 (VSS), LED3.3 (VSS), LED4.3 (VSS), LED5.3 (VSS), LED6.3 (VSS), LED7.3 (VSS), LED8.3 (VSS), LED9.3 (VSS), LED10.3 (VSS), LED11.3 (VSS), LED12.3 (VSS), LED13.3 (VSS), LED14.3 (VSS), LED15.3 (VSS), LED16.3 (VSS), LED17.3 (VSS), LED18.3 (VSS), LED19.3 (VSS), LED20.3 (VSS), MCU1.22 (GND), RE1.C, ROLL1.C, USB1.1 (GND), USB1.12 (GND), VIK_K1.2 (GND), VIK_K2.2 (GND), VIK_K3.2 (GND)
GNDA: DISP2.1 (GND), LED21.3 (VSS), LED22.3 (VSS), LED23.3 (VSS), LED24.3 (VSS), LED25.3 (VSS), LED26.3 (VSS), LED27.3 (VSS), LED28.3 (VSS), LED29.3 (VSS), LED30.3 (VSS), LED31.3 (VSS), LED32.3 (VSS), LED33.3 (VSS), LED34.3 (VSS), LED35.3 (VSS), LED36.3 (VSS), LED37.3 (VSS), LED38.3 (VSS), LED39.3 (VSS), LED40.3 (VSS), MCU2.22 (GND), RE2.C, ROLL2.C, USB2.1 (GND), USB2.12 (GND), VIK_K4.2 (GND), VIK_K5.2 (GND), VIK_K6.2 (GND)
GPIO1: DISP1.6 (DC), MCU1.18 (27), VIK_K1.7 (GPIO_AD1), VIK_K2.7 (GPIO_AD1), VIK_K3.7 (GPIO_AD1)
GPIO1_r: DISP2.6 (DC), MCU2.18 (27), VIK_K4.7 (GPIO_AD1), VIK_K5.7 (GPIO_AD1), VIK_K6.7 (GPIO_AD1)
GPIO2: DISP1.8 (BLK), MCU1.19 (28), VIK_K1.9 (GPIO_AD2), VIK_K2.9 (GPIO_AD2), VIK_K3.9 (GPIO_AD2)
GPIO2_r: DISP2.8 (BLK), MCU2.19 (28), VIK_K4.9 (GPIO_AD2), VIK_K5.9 (GPIO_AD2), VIK_K6.9 (GPIO_AD2)
I2C_3V3: JP1.1 (A), R1.1, R2.1
I2C_3V3_r: JP2.1 (A), R3.1, R4.1
LED: JP4.1 (A), LED1.4 (DIN), MCU1.20 (29)
LED_OUT: JP4.2 (B), LED20.2 (DOUT), VIK_K1.5 (RGB_LED_OUT), VIK_K2.5 (RGB_LED_OUT), VIK_K3.5 (RGB_LED_OUT)
LED_OUT_r: JP6.2 (B), LED40.2 (DOUT), VIK_K4.5 (RGB_LED_OUT), VIK_K5.5 (RGB_LED_OUT), VIK_K6.5 (RGB_LED_OUT)
LED_r: JP6.1 (A), LED21.4 (DIN), MCU2.20 (29)
MISO: DISP1.5 (RES), MCU1.13 (12), VIK_K1.11 (MISO), VIK_K2.11 (MISO), VIK_K3.11 (MISO)
MISO_r: DISP2.5 (RES), MCU2.13 (12), VIK_K4.11 (MISO), VIK_K5.11 (MISO), VIK_K6.11 (MISO)
MOSI/SCL: DISP1.4 (MOSI), MCU1.12 (11), R1.2, VIK_K1.4 (SCL), VIK_K1.8 (MOSI), VIK_K2.4 (SCL), VIK_K2.8 (MOSI), VIK_K3.4 (SCL), VIK_K3.8 (MOSI)
MOSI/SCL_r: DISP2.4 (MOSI), MCU2.12 (11), R3.2, VIK_K4.4 (SCL), VIK_K4.8 (MOSI), VIK_K5.4 (SCL), VIK_K5.8 (MOSI), VIK_K6.4 (SCL), VIK_K6.8 (MOSI)
unnamed: D1.2 (A), SW1.1
unnamed: D2.2 (A), SW2.1
unnamed: D3.2 (A), SW3.1
unnamed: D4.2 (A), SW4.1
unnamed: D5.2 (A), SW5.1
unnamed: D6.2 (A), SW6.1
unnamed: D7.2 (A), SW7.1
unnamed: D8.2 (A), SW8.1
unnamed: D9.2 (A), SW9.1
unnamed: D10.2 (A), SW10.1
unnamed: D11.2 (A), SW11.1
unnamed: D12.2 (A), SW12.1
unnamed: D13.2 (A), SW13.1
unnamed: D14.2 (A), SW14.1
unnamed: D15.2 (A), SW15.1
unnamed: D16.2 (A), SW16.1
unnamed: D17.2 (A), SW17.1
unnamed: D18.2 (A), SW18.1
unnamed: D19.2 (A), SW19.1
unnamed: D20.2 (A), SW20.1
unnamed: D21.2 (A), SW21.1
unnamed: D22.2 (A), SW22.1
unnamed: D23.2 (A), SW23.1
unnamed: D24.2 (A), SW24.1
unnamed: D25.2 (A), SW25.1
unnamed: D26.2 (A), SW26.1
unnamed: D27.2 (A), SW27.1
unnamed: D28.2 (A), SW28.1
unnamed: D29.2 (A), SW29.1
unnamed: D30.2 (A), SW30.1
unnamed: D31.2 (A), SW31.1
unnamed: D32.2 (A), SW32.1
unnamed: D33.2 (A), SW33.1
unnamed: D34.2 (A), SW34.1
unnamed: D35.2 (A), SW35.1
unnamed: D36.2 (A), SW36.1
unnamed: D37.2 (A), SW37.1
unnamed: D38.2 (A), SW38.1
unnamed: D39.2 (A), SW39.1
unnamed: D40.2 (A), SW40.1
unnamed: D41.1 (K), LED1.1 (VDD)
unnamed: D42.1 (K), LED21.1 (VDD)
unnamed: LED1.2 (DOUT), LED2.4 (DIN)
unnamed: LED2.2 (DOUT), LED3.4 (DIN)
unnamed: LED3.2 (DOUT), LED4.4 (DIN)
unnamed: LED4.2 (DOUT), LED5.4 (DIN)
unnamed: LED5.2 (DOUT), LED6.4 (DIN)
unnamed: LED6.2 (DOUT), LED7.4 (DIN)
unnamed: LED7.2 (DOUT), LED8.4 (DIN)
unnamed: LED8.2 (DOUT), LED9.4 (DIN)
unnamed: LED9.2 (DOUT), LED10.4 (DIN)
unnamed: LED10.2 (DOUT), LED11.4 (DIN)
unnamed: LED11.2 (DOUT), LED12.4 (DIN)
unnamed: LED12.2 (DOUT), LED13.4 (DIN)
unnamed: LED13.2 (DOUT), LED14.4 (DIN)
unnamed: LED14.2 (DOUT), LED15.4 (DIN)
unnamed: LED15.2 (DOUT), LED16.4 (DIN)
unnamed: LED16.2 (DOUT), LED17.4 (DIN)
unnamed: LED17.2 (DOUT), LED18.4 (DIN)
unnamed: LED18.2 (DOUT), LED19.4 (DIN)
unnamed: LED19.2 (DOUT), LED20.4 (DIN)
unnamed: LED21.2 (DOUT), LED22.4 (DIN)
unnamed: LED22.2 (DOUT), LED23.4 (DIN)
unnamed: LED23.2 (DOUT), LED24.4 (DIN)
unnamed: LED24.2 (DOUT), LED25.4 (DIN)
unnamed: LED25.2 (DOUT), LED26.4 (DIN)
unnamed: LED26.2 (DOUT), LED27.4 (DIN)
unnamed: LED27.2 (DOUT), LED28.4 (DIN)
unnamed: LED28.2 (DOUT), LED29.4 (DIN)
unnamed: LED29.2 (DOUT), LED30.4 (DIN)
unnamed: LED30.2 (DOUT), LED31.4 (DIN)
unnamed: LED31.2 (DOUT), LED32.4 (DIN)
unnamed: LED32.2 (DOUT), LED33.4 (DIN)
unnamed: LED33.2 (DOUT), LED34.4 (DIN)
unnamed: LED34.2 (DOUT), LED35.4 (DIN)
unnamed: LED35.2 (DOUT), LED36.4 (DIN)
unnamed: LED36.2 (DOUT), LED37.4 (DIN)
unnamed: LED37.2 (DOUT), LED38.4 (DIN)
unnamed: LED38.2 (DOUT), LED39.4 (DIN)
unnamed: LED39.2 (DOUT), LED40.4 (DIN)
RX: MCU1.2 (1), USB1.5 (DN2), USB1.7 (DN1)
RX_r: MCU2.2 (1), USB2.5 (DN2), USB2.7 (DN1)
SCLK/SDA: DISP1.3 (SCLK), MCU1.11 (10), R2.2, VIK_K1.3 (SDA), VIK_K1.12 (SCLK), VIK_K2.3 (SDA), VIK_K2.12 (SCLK), VIK_K3.3 (SDA), VIK_K3.12 (SCLK)
SCLK/SDA_r: DISP2.3 (SCLK), MCU2.11 (10), R4.2, VIK_K4.3 (SDA), VIK_K4.12 (SCLK), VIK_K5.3 (SDA), VIK_K5.12 (SCLK), VIK_K6.3 (SDA), VIK_K6.12 (SCLK)
SW_ENC: RE1.S2, ROLL1.S2, TP1.1
SW_ENC_r: RE2.S2, ROLL2.S2, TP2.1
TX: MCU1.1 (0), USB1.6 (DP1), USB1.8 (DP2)
TX_r: MCU2.1 (0), USB2.6 (DP1), USB2.8 (DP2)
col0: MCU1.3 (2), SW1.2, SW6.2, SW7.2, SW13.2
col0_r: MCU2.3 (2), SW21.2, SW26.2, SW27.2, SW33.2
col1: MCU1.4 (3), SW2.2, SW8.2, SW12.2, SW14.2
col1_r: MCU2.4 (3), SW22.2, SW28.2, SW32.2, SW34.2
col2: MCU1.5 (4), RE1.S1, ROLL1.S1, SW3.2, SW9.2, SW15.2, SW18.2
col2_r: MCU2.5 (4), RE2.S1, ROLL2.S1, SW23.2, SW29.2, SW35.2, SW38.2
col3: MCU1.6 (5), SW4.2, SW10.2, SW16.2, SW19.2
col3_r: MCU2.6 (5), SW24.2, SW30.2, SW36.2, SW39.2
col4: MCU1.7 (6), SW5.2, SW11.2, SW17.2, SW20.2
col4_r: MCU2.7 (6), SW25.2, SW31.2, SW37.2, SW40.2
row0: D1.1 (K), D2.1 (K), D3.1 (K), D4.1 (K), D5.1 (K), MCU1.17 (26)
row0_r: D21.1 (K), D22.1 (K), D23.1 (K), D24.1 (K), D25.1 (K), MCU2.17 (26)
row1: D7.1 (K), D8.1 (K), D9.1 (K), D10.1 (K), D11.1 (K), MCU1.16 (15)
row1_r: D27.1 (K), D28.1 (K), D29.1 (K), D30.1 (K), D31.1 (K), MCU2.16 (15)
row2: D13.1 (K), D14.1 (K), D15.1 (K), D16.1 (K), D17.1 (K), MCU1.15 (14)
row2_r: D33.1 (K), D34.1 (K), D35.1 (K), D36.1 (K), D37.1 (K), MCU2.15 (14)
row3: D6.1 (K), D12.1 (K), D18.1 (K), D19.1 (K), D20.1 (K), MCU1.14 (13)
row3_r: D26.1 (K), D32.1 (K), D38.1 (K), D39.1 (K), D40.1 (K), MCU2.14 (13)

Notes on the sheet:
I2C
Breakaways
VIK
MCU
Encoders
Split comm
Display
LEFT
RIGHT
Mounting holes

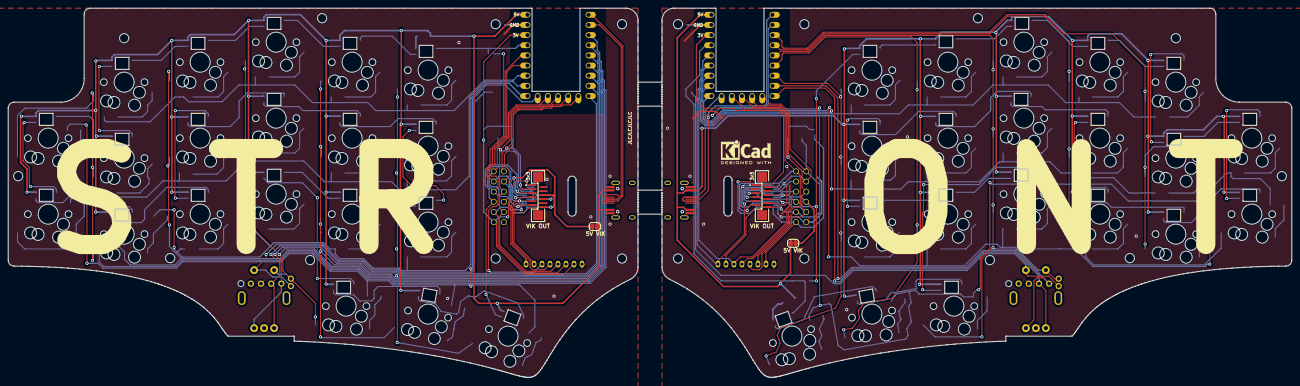
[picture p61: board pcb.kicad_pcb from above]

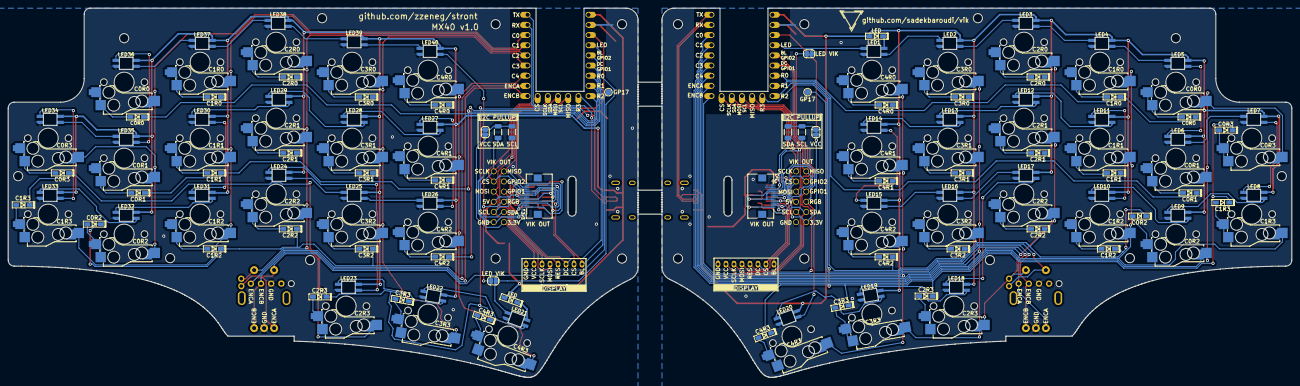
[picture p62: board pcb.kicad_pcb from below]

Board: 2 copper layers, 321.0 x 92.3 mm, 172 parts (94 on the bottom side), 134 nets.

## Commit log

2023-02-03 reversible incomplete
    [pcb.kicad_pcb, pcb.kicad_sch]
2023-02-03 non-reversible schematic
    [pcb.kicad_sch]
2023-02-06 draft 1
    [pcb.dxf, pcb.kicad_pcb, pcb.kicad_sch]
2023-02-28 component placement
    [pcb.kicad_pcb, pcb.kicad_sch]
2023-03-01 pcb left side
    [pcb.dxf, pcb.kicad_pcb]
2023-03-02 pcb right side
2023-03-04 add pull up resistors, additional holes
    [pcb.kicad_sch]
2023-03-05 small rework and resize
    [border.dxf]
2023-03-06 another resize
    [border.dxf, pcb.kicad_sch]
2023-03-07 update switch footprints
2023-03-07 final pcb
    [bottom-cutout.dxf, top.dxf]
2023-03-08 case STLs
    [bottom_case-choc v6_left-thin.stl, bottom_case-choc v6_left.stl, bottom_case-choc v6_right-thin.stl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]
2023-03-09 final case
    [bottom_case-choc v10_left-thin.stl, bottom_case-choc v10_left.stl, bottom_case-choc v10_right-thin.stl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]
2023-03-21 small case updates
    [bottom_case-choc v10_left-thin.stl, bottom_case-choc v10_left.stl, bottom_case-choc v10_right-thin.stl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]
2023-06-09 Add MX version
    [pcb.kicad_pcb, pcb.kicad_sch]
2023-06-10 production files
    [BOM-pcb.csv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]
2023-06-10 small updated
    [pcb.kicad_pcb]
2023-06-10 3x5 version
    [BOM-pcb.csv, pcb.kicad_pcb, pcb.kicad_sch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]
2023-06-11 update components
    [BOM-pcb.csv, pcb.kicad_pcb, pcb.kicad_sch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]
2023-06-11 fix diode placement
    [CPL-pcb.csv]
2023-06-14 small updates
    [CPL-pcb.csv]
2023-06-17 hole updates
    [BOM-pcb.csv, pcb.kicad_sch]
2023-06-23 new jumper for VIK
    [pcb.kicad_sch]
2023-06-24 fix PCBA placement
    [CPL-pcb.csv]
2023-06-24 add trackball adapter
    [BOM-pcb.csv, pcb.kicad_pcb, pcb.kicad_sch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]
2023-06-25 add case
    [bottom_left-thick.stl, bottom_left.stl, bottom_right-thick.stl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]
2023-07-09 actually final case
    [bottom_left-shell.stl, bottom_left-thick-shell.stl, bottom_left-thick.stl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]
2023-07-25 small case and cover updates
    [bottom_left-shell.stl, bottom_left.stl, bottom_right-shell.stl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]
2023-08-25 small case updates (untested)
    [bottom_left-honeycomb.stl, bottom_left.stl, bottom_right-honeycomb.stl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]
2024-01-20 remove untested case, add azoteq covers
    [azoteq-tps43.stl, azoteq-tps65-left.stl, azoteq-tps65-right.stl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]
2024-02-16 small improvements for azoteq covers - tested
    [azoteq-tps43.stl, azoteq-tps65-left.stl, azoteq-tps65-right.stl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]
2024-03-11 add first version
    [bottom_case-mx40 v3_left.stl, bottom_case-mx40 v3_right.stl, outline.dxf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]
2024-03-11 fix case
    [bottom_case-mx40 v3_left.stl, bottom_case-mx40 v3_right.stl, bottom_left.stl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]
2024-03-18 fix file names
    [bottom_left.stl, bottom_right.stl]
2024-04-04 improve routing, rename case files
    [pcb.kicad_pcb, top_left-roller_plateHeight_2.5mm.stl, top_left-roller_plateHeight_5mm.stl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]
2024-04-07 replace vertical VIK footprint for easier soldering
    [pcb.kicad_pcb, pcb.kicad_sch]
2024-04-08 update 38keys to kicad 8, small routing updates, update libs
    [pcb.kicad_pcb, pcb.kicad_sch]
2024-04-08 add led position files
    [mx38-pcb-all-pos.xlsx, mx40-pcb-all-pos.xlsx]
2024-04-08 update readmes, restructure
    [BOM-pcb.csv, azoteq-tps43.stl, azoteq-tps65-left.stl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]
2024-04-19 update covers and mx40 bottom case
    [azoteq-tps43.stl, azoteq-tps65-left.stl, azoteq-tps65-right.stl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]
2024-04-24 update PCB silkscreen, fix readme
    [pcb.kicad_pcb]
